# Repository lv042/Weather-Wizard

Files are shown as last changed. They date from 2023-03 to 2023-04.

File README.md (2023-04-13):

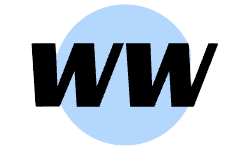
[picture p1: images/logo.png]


# WeatherWizard

WeatherWizard is an Internet of Things (IoT) project that collects and analyzes weather data in real-time. The project is designed to provide users with accurate and up-to-date weather information, as well as insights into climate trends over time.

# Features

- Collects weather data in real-time
- Displays weather data on a web page
- Admin panel to manage the WeatherWizard
- Email notifications
- API Route analytics
- Provides insights into climate trends over time

### Weather measurements:

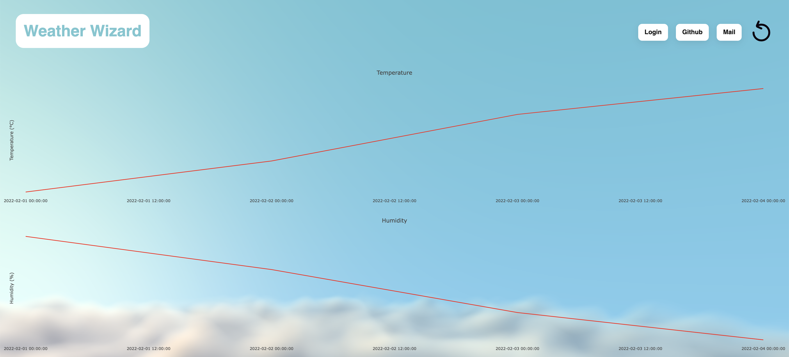
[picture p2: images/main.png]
Weather measurements


### Admin panel:

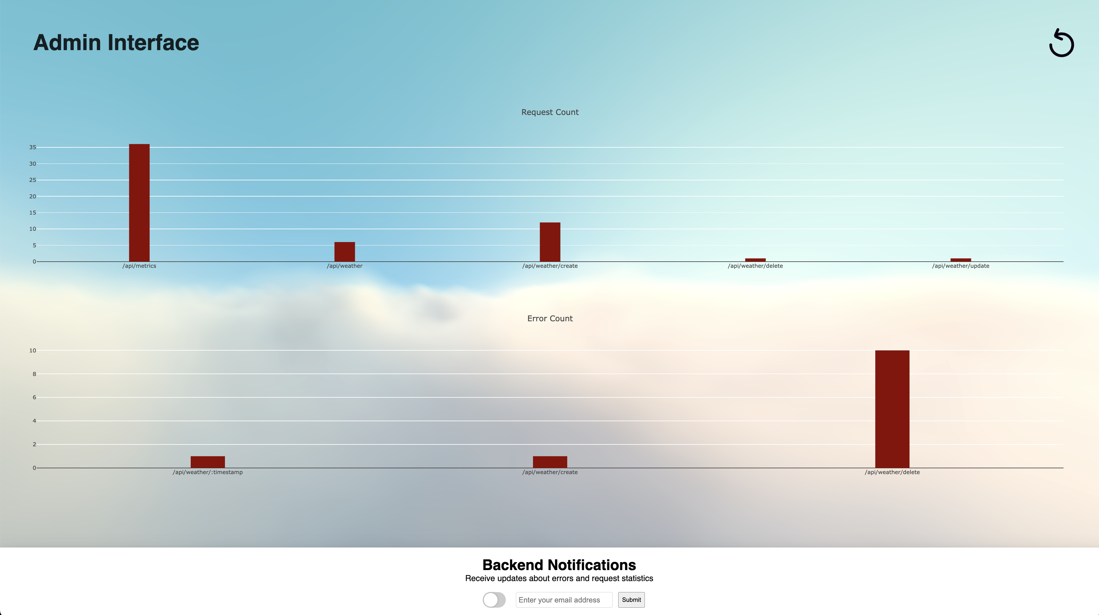
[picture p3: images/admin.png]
Admin panel


### Embedded device:

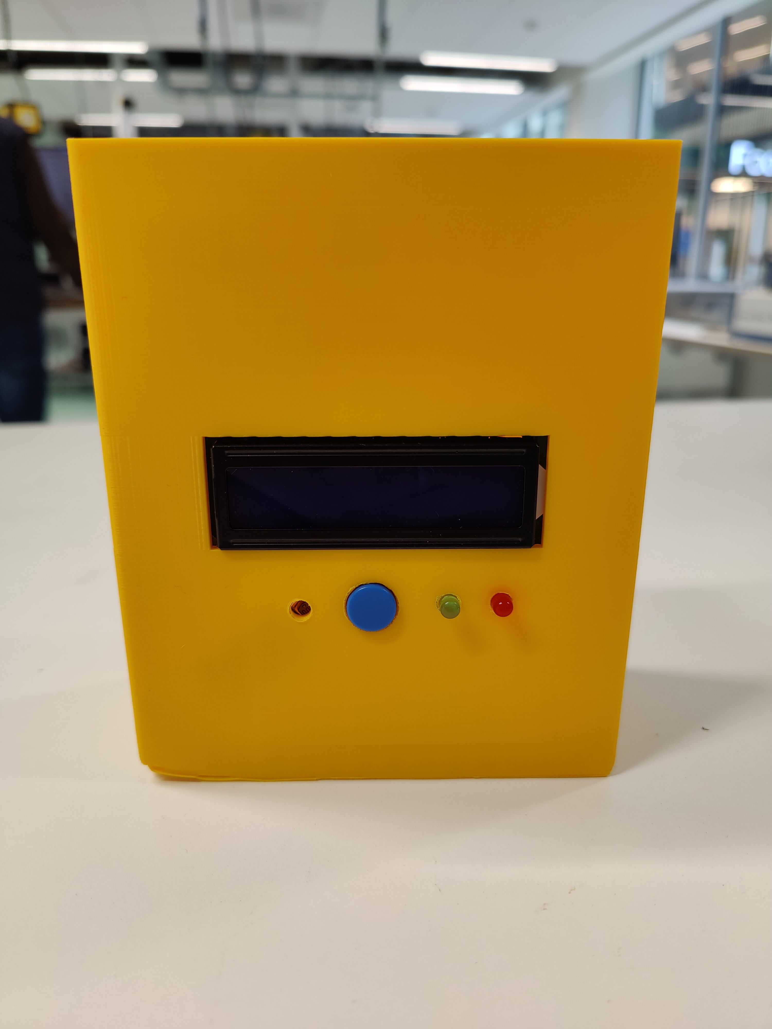
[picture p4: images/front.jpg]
Embedded device


# Getting Started
Clone the WeatherWizard repository and to and follow the instructions provided in the [User manual](./user_manual.md).

# Documentation

The documentation of the project is divided into the following sections:

### General:
- [User manual](./user_manual.md)
- [Architecture overview](./architecture_overview.md)

### Embedded device:
- [System requirements](./system_requirements.md)
- [Software](./emb_software.md)
- [Wiring Diagram & BOM](./bom.md)

### Web application:
- [Database](./db.md)
- [Frontend](./frontend.md)
- [Backend API](./backend.md)
- [New Backend](./improvement.md)

### Physical design:
- [Concept](./physical_design.md)
- [Creation](./creation.md)
- [Failures](./failures.md)

### Research:
- [Research question](./research_question.md)
- [Research](./research.md)
- [Backend implementation](./improvement.md)
- [Changelog](./changelog.md)

# License
WeatherWizard is released under the [Apache License 2.0](./LICENSE).

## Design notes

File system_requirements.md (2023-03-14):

# System Requirements
(Reviewed by Rafail)

## EMBRQ#01
After measuring the data the sensors provide, the data gets send to the server with the "send_data(temperature, humidity, 0, 0, light);"
function. The server then stores the data in a database. The data is then displayed on the website.

POST request:

```json
{
  "timestamp": "2022-03-07 12:00:00",
  "temperature": 25,
  "humidity": 70,
  "pressure": 1013,
  "obstacle_detected": false,
  "light_intensity": 100
}
```

Not all the data is actually collected by the wemos, but it allows for future expansion.

Code:
```cpp
void send_data(float temperature, float humidity, float pressure, int obstacle_detected, float light_intensity) {
  // create the JSON payload string
  String payload = "{\"timestamp\":\"current_time,\"temperature\":" + String(temperature) + ",\"humidity\":" + String(humidity) + ",\"pressure\":" + String(pressure) + 
  ",\"obstacle_detected\":" + String(obstacle_detected) + ",\"light_intensity\":" + String(light_intensity) + "}";
  
  // specify the target URL
  httpClient.begin(client, "https://abc3.loca.lt/index.php?action=weather_data");
  
  // set the content type header to JSON
  httpClient.addHeader("Content-Type", "application/json");
  
  // send the POST request with the JSON payload
  int httpCode = httpClient.POST(payload);
  
  // check if the request was successful
  if (httpCode == HTTP_CODE_OK) {
    Serial.println("Data sent successfully!");
  } else {
    Serial.println("Error sending data!");
  }
  
  // free resources
  httpClient.end();
}
```

## EMBRQ#02
The wemos is able to do a get request to do backend server to ask for a config file. The config file looks currently like this:
```json
{
  "timeout": 5000,
  "retry_count": 3,
  "debug_mode": true
}
```

Code:
```cpp
void get_config(){
  httpClient.begin(client, "https://abc3.loca.lt/index.php?action=config"); // Set up HTTP GET request to server
  int httpCode = httpClient.GET(); // Send HTTP GET request and store response code

  if(httpCode == HTTP_CODE_OK) { // Check if response is successful
    String payload = httpClient.getString(); // Get response payload
    Serial.println(payload); // Print payload to serial monitor
  } else {
    Serial.println("Unable to connect :("); // Print error message if response is unsuccessful
  }

}
```

## EMBRQ#03
The wemos uses the humidity and temperature sensor to measure the temperature and humidity. The light sensor is used to measure the light intensity.
A button is used to turn the Weather Wizard on and off.

Humidity/Temperature and light intensity sensor:
```cpp
void read_sensors(){
  // Humidity is measured
  humidity = dht.readHumidity();
  // temperature is measured
  temperature = dht.readTemperature();
  // light
  light = analogRead(light_intensity_sensor); 
   
  // Checking if the measurements have passed without errors
  // if an error is detected, a error message is displayed here
  if (isnan(humidity) || isnan(temperature)) {
    Serial.println("Error reading the sensor");
    return; /quits the function
  }
}
```

Button:
```cpp
void button_input(){
  int buttonState = digitalRead(buttonPin);

  // If the button is pressed, set running_ww to true
  if (buttonState == HIGH) {
    running_ww = true;
  } else {
    running_ww = false;
  }
}
```

## EMBRQ#04
The Weather Wizard uses the LCD screen to display the temperature, humidity. Furthermore, it has two LEDs, one which is green and one which is red. The green LED is used to indicate that the Weather Wizard is on.
The red LED is used to indicate that the Weather Wizard is off.

Function to display the temperature and humidity on the LCD screen:
```cpp
void run_lcd(){
  lcd.setCursor(0, 0);
  lcd.setBacklight(HIGH);
  // print message
  lcd.print("Temp: ");
  
  char temp_c[5];
  lcd.print(dtostrf(temperature, 3, 2, temp_c));
  
  // set cursor to first column, second row
  lcd.setCursor(0,1);
  lcd.print("Humidity: ");
  
  char hum_c[5];
  lcd.print(dtostrf(humidity, 3, 2, hum_c));
  lcd.print("%");
}
```

Main loop of the Weather Wizard to turn the LEDs on and off:

If Weather Wizard is running the green LED is turned on and the red LED is turned off.
If the Weather Wizard is not running the green LED is turned off and the red LED is turned on.

```cpp
void loop(){
  //check if the button was pressed to turn on Weather Wizard
  button_input();

  if(running_ww){
    //turns on the green LED if the Weather Wizard is running
    digitalWrite(led_red, LOW);
    digitalWrite(led_green, HIGH);

  //after doing a get request the backend sends config file 
  get_config(); // Function to get configuration file from server
  //send data with a post request
  send_data(temperature, humidity, 0, 0, light); // Function to send sensor data to server
    
  run_lcd(); // Function to update LCD screen with sensor data
  read_sensors(); // Function to read sensor values

  //waits 2 sec till it makes new measurements
  delay(2000); // Delay before taking new measurements
  lcd.clear(); // Clear LCD screen
  //lcd clears the screen again
  }
  else{
    //turn on the red light and turn off the green light
    digitalWrite(led_red, HIGH);
    digitalWrite(led_green, LOW);
  }
}
```

## EMBRQ#05
This function sets up the Wi-Fi manager, which allows the user to connect to the Weather Wizard via a web interface. The user can then enter the SSID and password of the Wi-Fi network they want to connect to.
Code:
```cpp
void setup_wifi_manager() {
  WiFiManager wifiManager; // Create a Wi-Fi manager object
  bool con = wifiManager.autoConnect("WeatherWizard AutoConnect", "password"); // Attempt to connect to Wi-Fi using saved credentials or create a new AP with the specified SSID and password
  pinMode(LED_BUILTIN, OUTPUT); // Set the built-in LED pin to output mode

  if(!con) {
      Serial.println("Failed to connect."); // Print error message if unable to connect to Wi-Fi
      digitalWrite(LED_BUILTIN, HIGH); // Turn on LED to indicate error
  } 
  else {
      Serial.println("Connected..."); // Print success message if connected to Wi-Fi
      Serial.println(WiFi.localIP()); // Print the IP address of the device
      digitalWrite(LED_BUILTIN, LOW); // Turn off LED to indicate successful connection
  }
}
```

## Full code 

Go to:

```
./emb/src/main/main.ino
```

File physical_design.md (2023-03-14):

(Reviewed by Rafail)
# Concept

## Target group

The user of the WeatherWizard can be anyone who is interested in monitoring and recording weather data from a specific location. This could include:

- Farmers and agricultural workers who need to track weather patterns for crop management and irrigation purposes.

- Transportation and logistics companies that need to monitor weather conditions to optimize their routes and delivery schedules.

- Construction companies that need to plan their projects around weather conditions.

- Weather enthusiasts who want to track weather data for personal interest or research purposes.

- Government agencies that need to monitor weather conditions for disaster preparedness and response.

## Needs and Goals

- Weather resistance: Since the WeatherWizard is constantly exposed to various weather conditions such as rain, sunlight, wind, etc., the housing should be robust and weather-resistant to protect the sensors and electronics from damage.

- Waterproofing: The enclosure should be waterproof to prevent water from entering the enclosure and damaging the sensors or electronics.

- Space requirement: The enclosure should provide enough space to accommodate all sensors, batteries, and transmission technology.

- Material: The enclosure material should be robust, durable, and corrosion-resistant to ensure a long life for the WeatherWizard -> ABS plastic

- Mounting options: The enclosure should provide suitable mounting options to mount the WeatherWizard in a suitable location, such as on a wall or pole.

- Access to the interior: The housing should allow easy access to the inside to replace or maintain the batteries or electronics if necessary.

- Easy assembly: The enclosure should be easy to assemble, disassemble, and transport, making it convenient for installation and relocation.

- Cost: The enclosure should be cost-effective to ensure that the WeatherWizard can be manufactured at a reasonable price.

- Noise reduction: The housing should be designed to reduce any noise or vibration caused by the sensors or electronics, which can affect the accuracy of the collected data. (Altough there are no moving parts in the WeatherWizard by now)

- Ventilation: The enclosure should be designed to allow for proper ventilation to allow accurate measerments by the sensors.

- Aesthetics: The enclosure should be designed to be aesthetically pleasing to ensure that the WeatherWizard is not an eyesore.

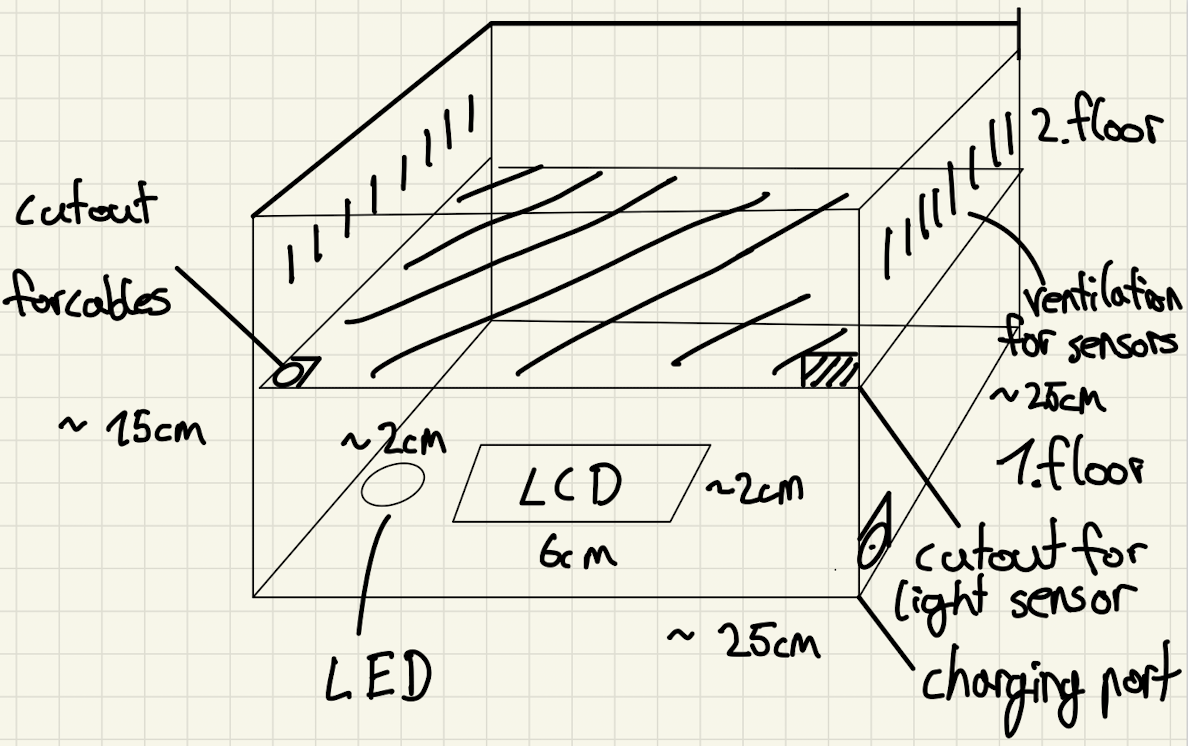
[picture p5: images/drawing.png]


The design is seperated in two floors the first floor is for the main hardware and the second is for the sensors. The reason for that is that some of the sensors need ventilation to make more accurate messearments.

## Smart requirements

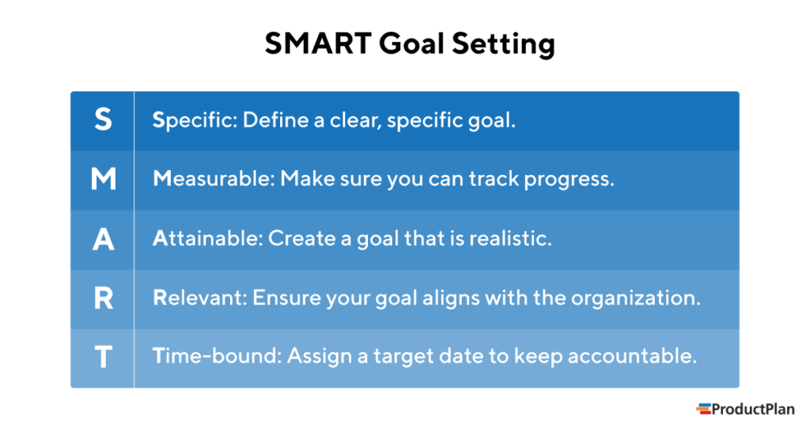
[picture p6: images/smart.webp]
Smart


Specific: All the goals mentioned above are specific and clear.

Measurable: I made a timeline in the docks, where I can see how much time I spend on each part of the project.

Attainable: All the requirements mentioned above are realistic and achievable.

Relevant: All the requirements mentioned above are relevant to the project.

Time-bound: My time target is to finish the physical design in one week before the deadline, so I still have time to make changes and improvements.

# Digital manufacturing materials and methods

## The chosen device

3D printing is a process in which a digital 3D model is converted into a physical object layer by layer using a 3D printer. To do this, the printer uses different materials, such as plastics or metals, which are applied layer by layer and fused together.

## The chosen material

For the enclosure of the weather station, ABS (Acrylonitrile Butadiene Styrene).  ABS is known for their high strength, durability, and resistance to impact and weathering, making them ideal for protecting the sensitive electronic components of the WeatherWizard from the elements.

## Reasons for the selected production:

- Customizability: 3D printing allows for easy customization of the design of the weather station chassis, enabling the creation of unique and specialized designs to meet specific requirements (Altough the shape is right now very simple, but it might be changed in the future)

- Speed: 3D printing allows for fast production of the weather station chassis, with the ability to print parts on demand and with minimal lead time.

- Cost-effective: 3D printing is a cost-effective option for producing a small casing the weather station chassis (The final draft of the weather station which is currently printing, costed me 10 euro's)

- Durability: 3D printing allows for the production of durable parts that can withstand the elements and last for a long time.

## Disadvantages of the selected production:

- Limited material choices: While 3D printing has come a long way in terms of materials, the range of available materials is still limited compared to traditional manufacturing methods.
- Hard to repair: 3D printing is not suitable for repairing broken parts.
- Hard to recycle: 3D printing is not suitable for recycling.
- Limited print size: The size of 3D printed objects is limited by the size of the 3D printer.
- Limited production speed: 3D printing can be a slow process, especially for large objects.

# DIGITAL DESIGN

## Chosen software

First I used Tinkedcad, but later switched to FreeCAD. I used FreeCAD because it is more powerful and has more features. Tinkercad might be better for beginners, but FreeCAD is more suitable for more complex designs.

Update: Unfortunately I had to switch back to Tinkercad because FreeCAD learning curve is too steep for the time I have left.

## Stages of the design process

1. Determine the purpose and requirements of the casing
2. Take accurate measurements
3. Create a 3D model of the object using CAD software
4. Select the appropriate printer and material
5. Slice the 3D model into layers using slicing software
6. Set the printing parameters, such as the layer height and printing speed
7. Send the sliced model to the 3D printer and start the printing

# Project files of the design

Go to:
```
./physical-design/........
```

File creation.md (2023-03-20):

# Physical Design - Create

(Reviewer Luca(not me))

## Requirements

The most important requirements are for me:

- The device should be able to withstand the weather conditions in the Netherlands
- Weather Wizard should have cutouts for the sensors, button, led's and the LCD screen
- The casing should be easy to assemble after printing
- The casing should be easy to print
- Weather Wizard should provide a lot of space to be expandable with more sensors
- The casing should have a ventilation hole to guarantee accurate sensor readings

## Testing

Criteria I can test:

- The casing should be easy to assemble after printing -> You just have to plug in sensors, button, led's and the LCD screen and
glue the roof on the casing

- Measurements -> All the components fit in the casing as shown later in the final design

- Aesthetics -> The casing looks nice and is easy to print

- Ventilation for sensor readings -> The casing has a ventilation hole at the bottom of the casing

- Rain test -> I put the casing in the shower, and it was still working after 10 minutes

Update: I have tested the case in the rain, and it is not completely waterproof, but rather water-resistant . I think that the optimal solution for this problem would be to use hot glue to seal the ceiling of the case.
This is an image of before the test:

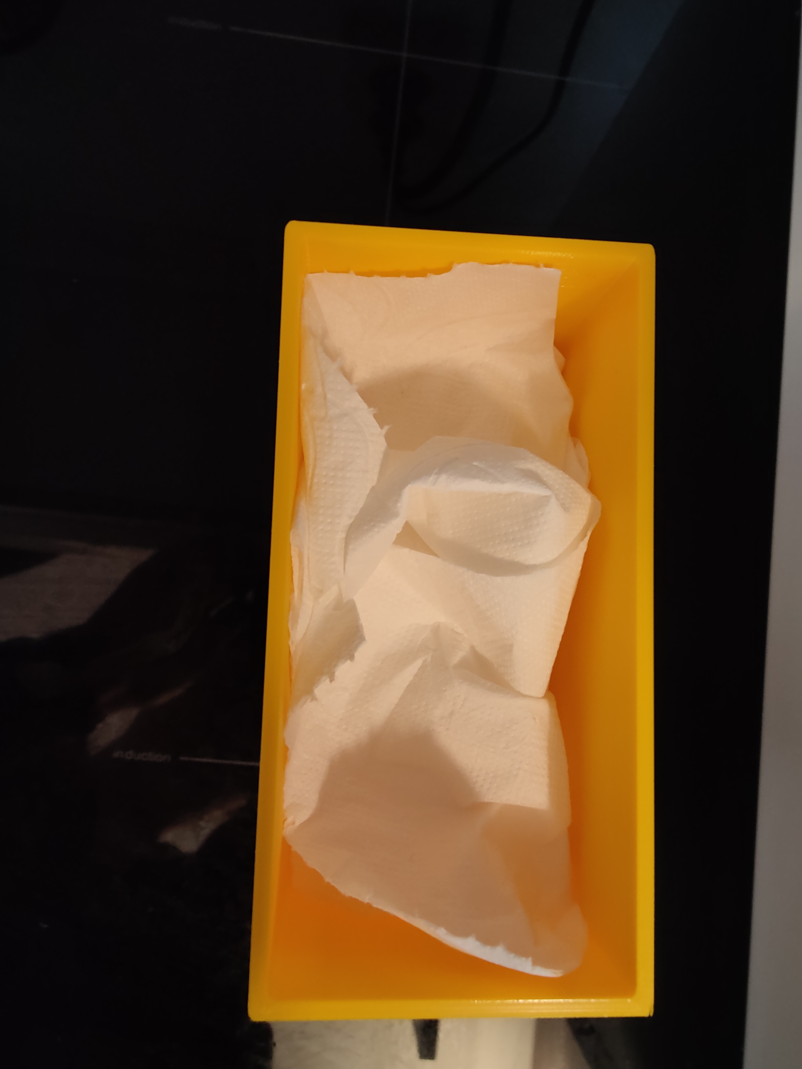
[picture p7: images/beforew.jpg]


This is an image during the test:

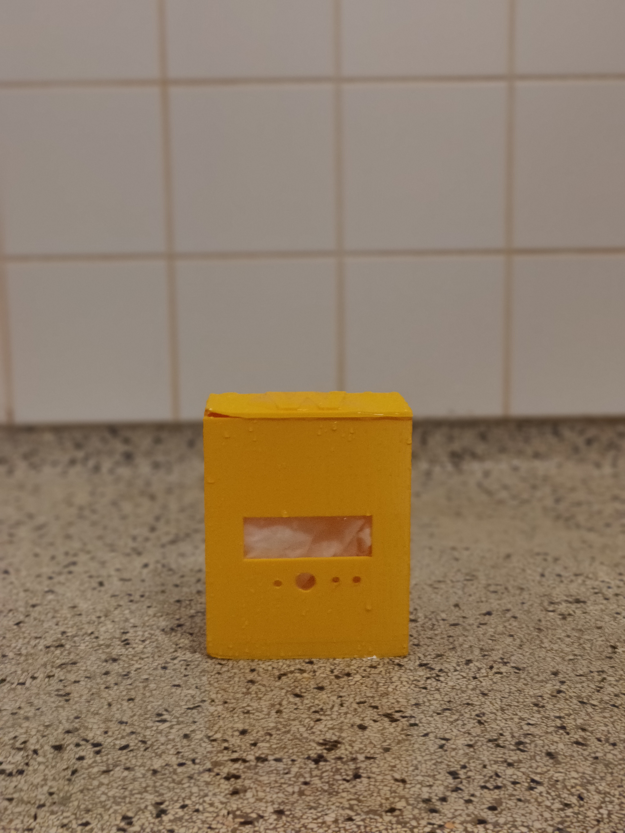
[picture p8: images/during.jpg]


This is an image after the test:

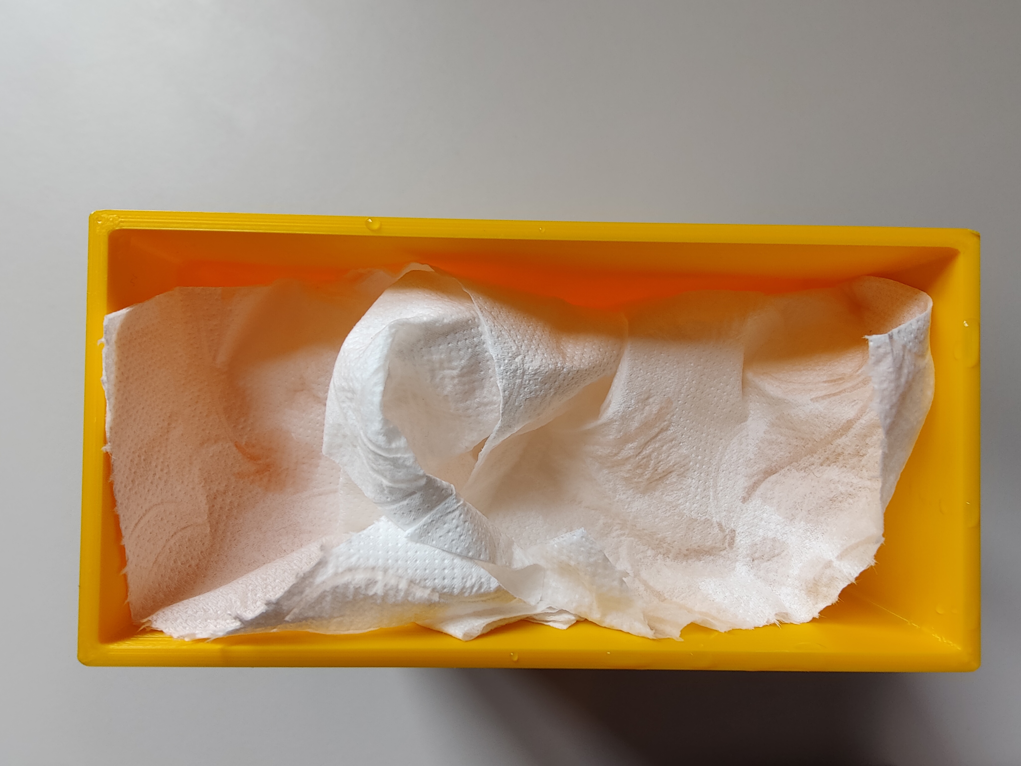
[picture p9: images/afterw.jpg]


You can clearly see that some water got inside the casing, but not enough that you can't hot glue the ceiling of the casing.

- Drop test -> I dropped the casing from 1 meter for 20 times, and the casing was still intact

Update: These are images of the casing after the drop test:

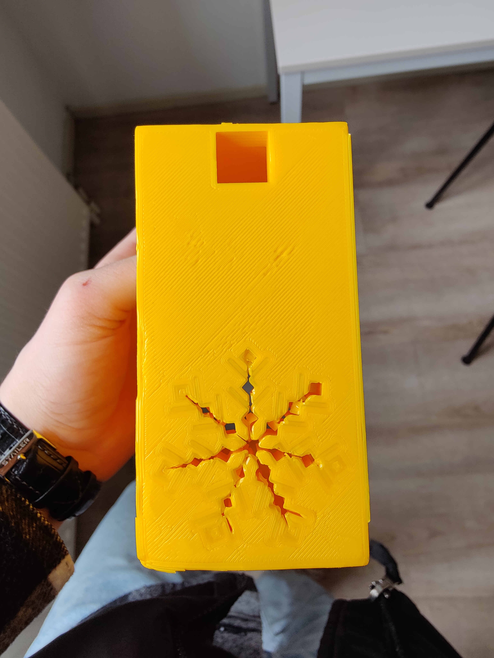
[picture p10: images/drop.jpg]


You can see that there are no major damages to the casing. The scratches in the bottom are probably rather from printing errors than from the drop test. In my opinion the casing can withstand most environmental conditions as long as it is made waterproof.

After performing the drop test, I noticed that the casing was not completely intact. The casing was still working, but the casing was not as sturdy as I thought it would be. I think that the optimal solution for this problem would be to use hot glue to seal the ceiling of the case.

- Space for expansion -> The casing has a lot of space to be expandable with more sensors

- Assembly -> Weather Wizard is very easy to print. The files for the 3D-printer are provided and it is easy to assemble afterwards

## Prototype

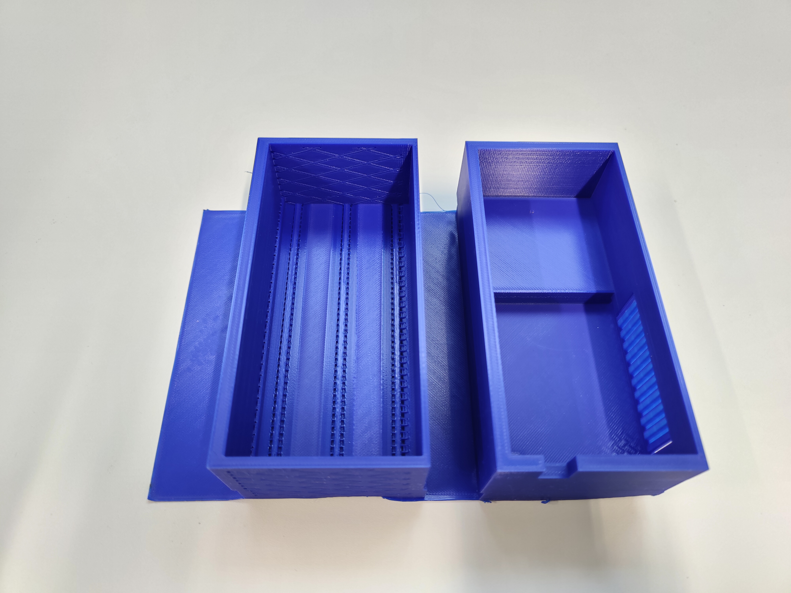
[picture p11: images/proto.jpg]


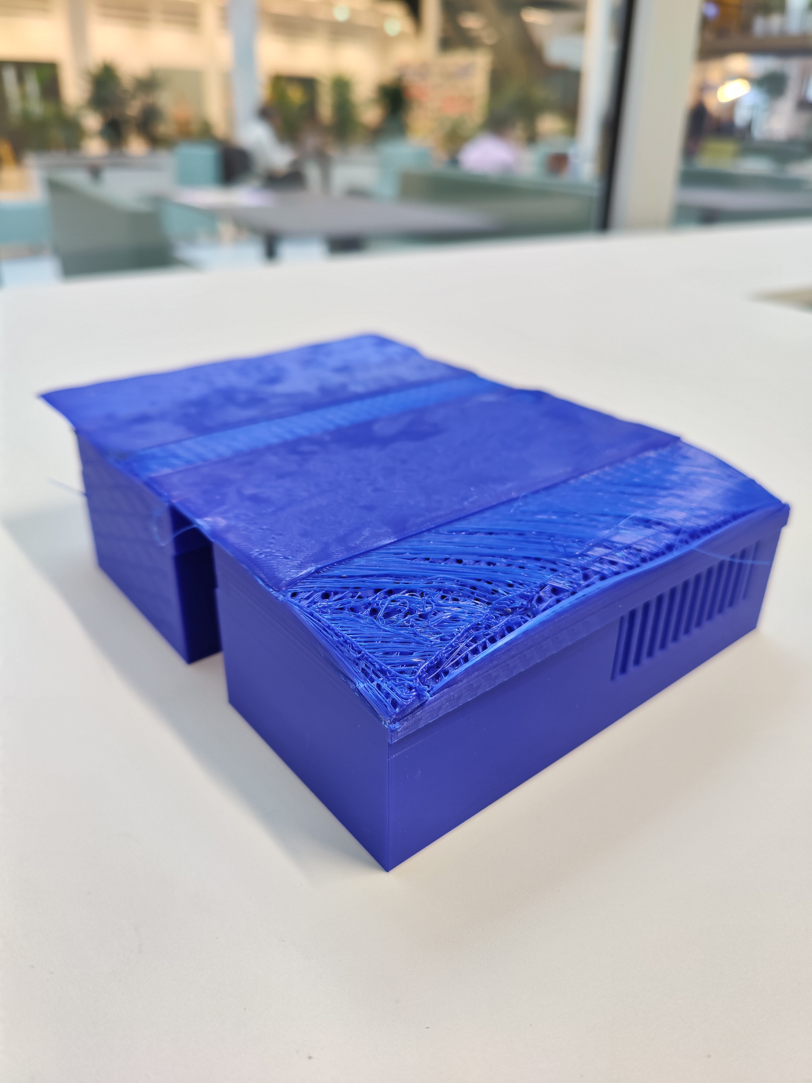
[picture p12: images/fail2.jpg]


Although this prototype already looks quite good. I still want to make some changes to the casing. The changes include: 

- Merging the two smaller cases into one big case to make it easier to print and assemble

- Putting the ventilation hole at the bottom of the casing, so rainwater can't get inside the casing like before

- Removing the holes from the print, but instead drill the holes in the casing after printing which is easier to do and more accurate

- Improve printing quality -> The bottom of the prototype is not printed well, so I want to improve the printing quality

## Final Design

First, after merging the two smaller cases and adding the ventilation at the bottom, this was the design:

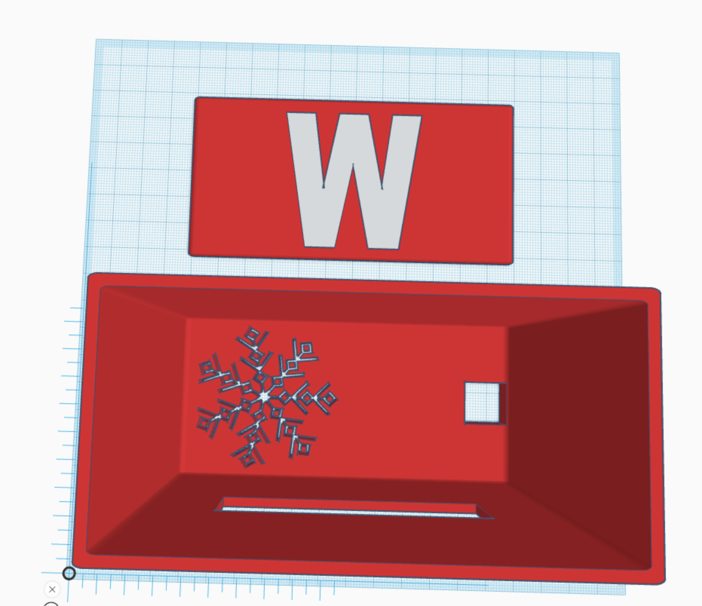
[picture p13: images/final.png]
Final Design


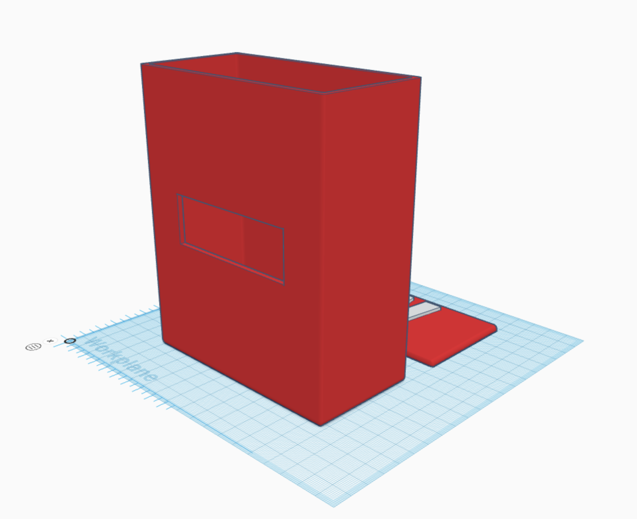
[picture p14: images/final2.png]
Final Design


A snowflake made a great shape for the ventilation hole, because it was easy to print and was fitting for a weather station. The
W on the top of the casing stands for Weather Wizard. The other cutout at the bottom is for the cable of the Wemos d1 mini.

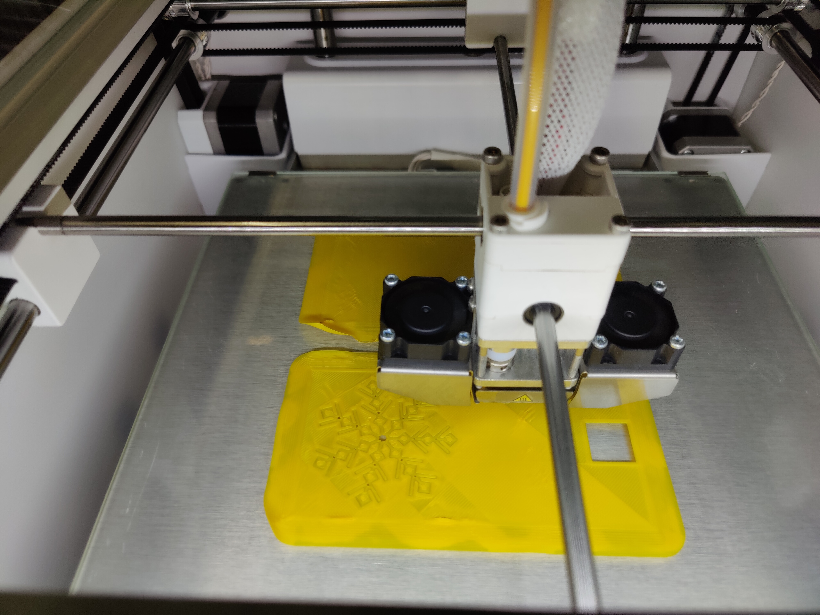
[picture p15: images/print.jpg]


This was the first print of the casing. Although the print had some imperfections, it was good enough for the final version.
I used a 0.2 mm layer height and 20% infill. The print took about 17 hours and 30 minutes. The print was made with PLA filament.
I used auto generated support for the snowflake and the hole of the lcd screen. The support was easy to remove afterwards. The whole 
casing was printed on a brim, so it would stick to the build plate. The Cura slicer was used for the slicing and the printer was a
Ultimaker 2+ Connect.

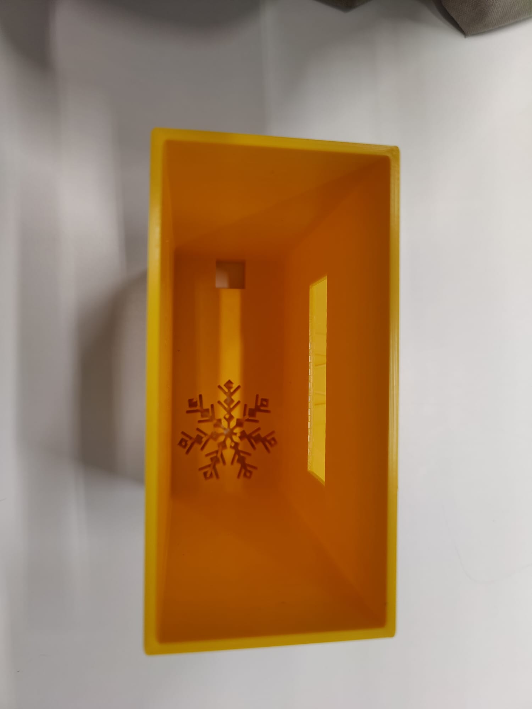
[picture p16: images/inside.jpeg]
Inside


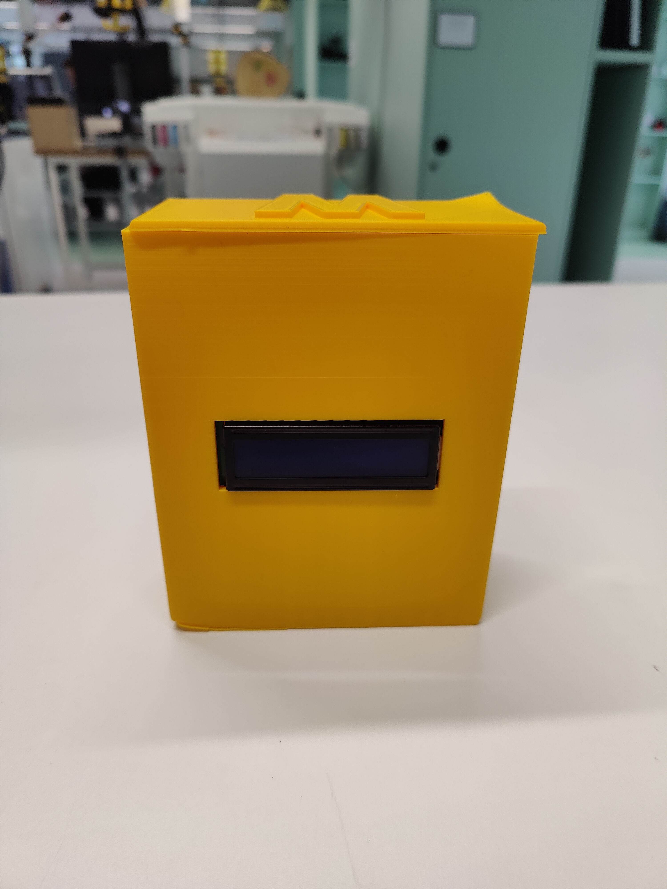
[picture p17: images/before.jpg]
Before


This was the first look of the casing after printing and inserting the lcd screen.

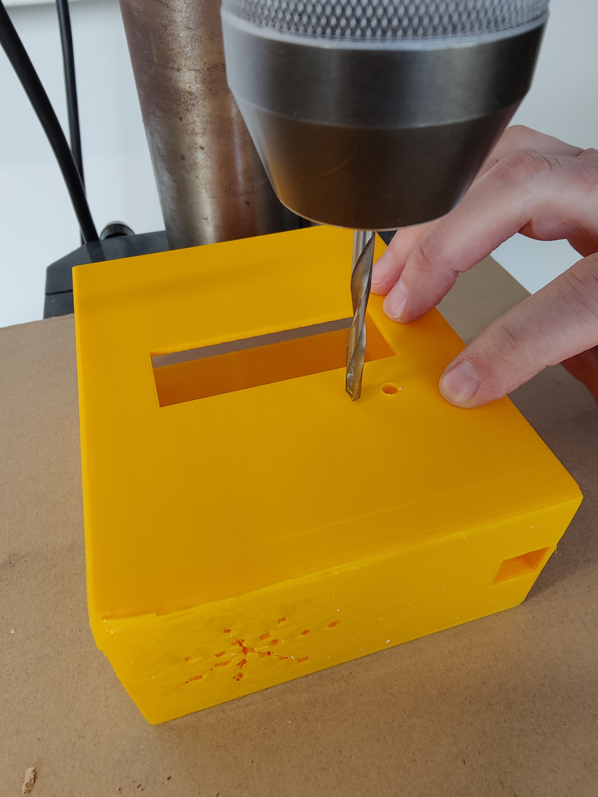
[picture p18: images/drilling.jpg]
drilling


Next, I still had to drill the holes for the sensors, button, led's and the LCD screen. Firstly, I measured the length of the components
and marked the holes on the casing. Then I compared the measurements with the drill bits I had. I used a 3mm and 5 mm drill bit for the
the sensors and led's. The button needed the 5 mm drill bit. It is important that a drill bit for plastic is used, otherwise you will
damage the drill bit. 

After

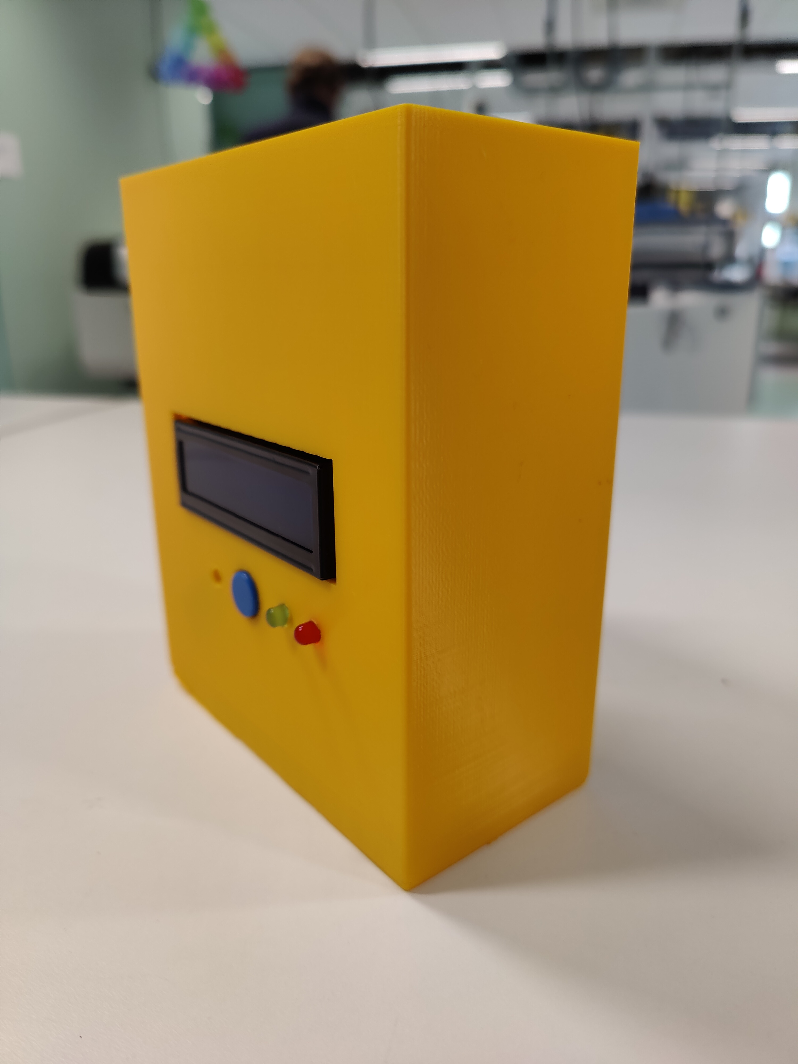
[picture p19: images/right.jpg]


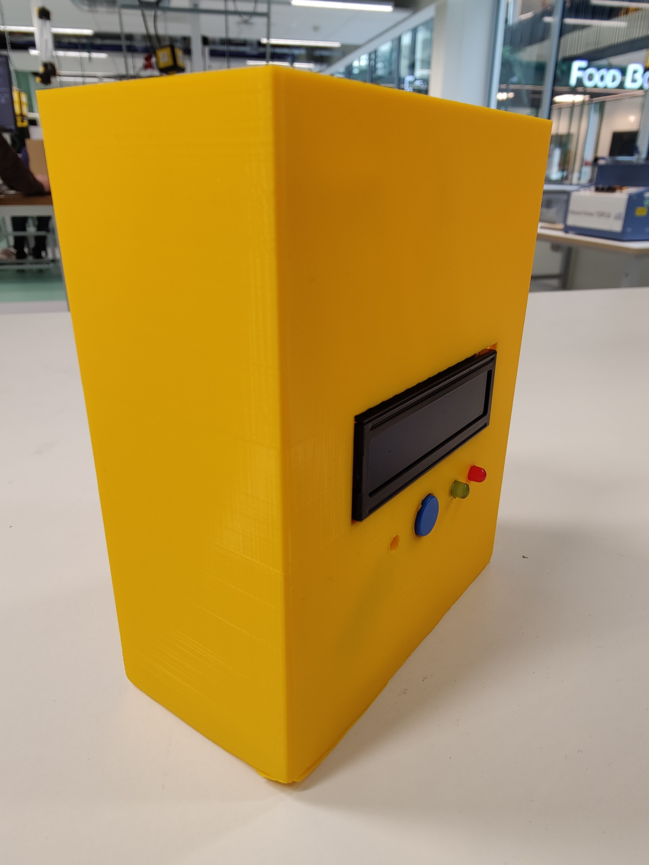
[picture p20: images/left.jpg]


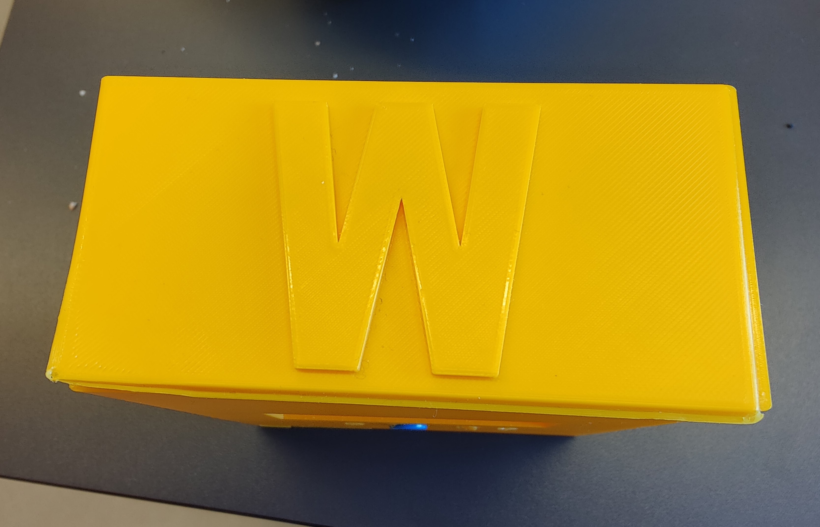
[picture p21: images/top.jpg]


For the final version, I would glue the components with hot glue to make sure they don't fall out of the casing, but 
for now I duck taped them in the casing, because I still want to use the components after the project.

## Manufacturing process

I printed in with the quality setting, which already took 17 hours and 30 minutes. To have more detail you could print with the smallest nozzle, but
this would take more than 24 hours to print and would cost way too much time for the blueprint phase.

#### Chosen material 

I chose PLA yellow Ultimaker filament, because:

- It is easy to print with
- It is easy to remove the support
- It is easy to glue the components in the casing
- It is easy to drill the holes in the casing
- It is environmentally friendly
- It is cheap
- It allows for a wide range of colors and finishes

#### Manufactoring device

The main reason, because I printed with the Ultimaker 2+ Connect, is because it was the main printer of the Makerslab, but it is also a good printer.

Most of its special features, I didn't even have to use:

- Single extrusion with swappable nozzles
-  Cloud-enabled remote 3D printing
-  Filter up to 95% of UFPs (optional)
-  Print with 9 materials (including PP & PC)

#### Logging of the manufacturing process is described

Of course, I could only log the beginning of the print and the final product of the print, because the print always was running the whole night.

#### Files

The stl files contain the basic structure of the file and the 
ufp files contain the additional information for the printer. 
The ufp files are used to print the casing with the Ultimaker 2+ Connect.

The files can be found here in the root of the repo:
```
./physical-design
```

Prototype files:

- [Prototype.ufp](./physical-design/prototype.ufp)
- [Prototype 0.1.stl](./physical-design/prototype%200.1.stl)
- [Prototype 0.15.stl](./physical-design/prototype%200.15.stl)
- [Prototype 0.2.stl](./physical-design/prototype%200.2.stl)
- [Prototype 0.25.stl](./physical-design/prototype%200.2%20rotated.stl)

Final design:

- [Final Design.ufp](./physical-design/Weather%20Wizard%20Final.ufp)
- [Final Design.stl](./physical-design/Weather%20Wizard%20Final.stl)

#### Optimisations during the manufacturing process:

- During the print one of the early models was not compatabile with the printer, because the required support was too big for the printer, and coudln't be removed afterwards. So I had to redesign the casing to make it compatible with the printer.
- I drilled the holes of the casing, instead of printing them, because it was easier to do, more accurate and allowed more flexibility for the components.
- After using the printing option with the smallest nozzle, which took longer than 24 hours, I decided to use the normal quality option, which took 17 hours and 30 minutes. This was a good compromise between time and quality, because
the quality was good enough for the final version.

#### Future possible Optimisations

- For mass production, I would use a different printer, because the Ultimaker 2+ Connect is not the fastest printer, and it is not the cheapest printer, but also including the holes in the casing 
would make the assembly easier and more accurate.

- More accurate holes for the components

- Glue the components in the casing with hot glue

- More accurate printing quality, could be achieved by printing with a smaller nozzle size

#### Reached Requirements

All the mentioned requirements are reached, except for the easy printing, because the time to print is quite long. But the print is easy to assemble afterwards.

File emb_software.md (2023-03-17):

# Embedded Software

(Reviewed by Rafail)

This document describes the embedded software of the Weather Wizard. The embedded software is the code that runs on the microcontroller. The microcontroller is the brain of the Weather Wizard. It is responsible for reading the sensors, displaying the data on the LCD screen, and sending the data to the backend.

## Information about the code 

Program code contains comment in the top the file stating author information, license type, and goal of this part of the program and has a nice readable layout. License type is an existing license type like FreeBSD, or CC, or individual copyright (C) containing a year.

```
/* Author: Luca von Kannen
 * License: Apache License, version 2.0.
 * Goal: This file contains code to operate the WeatherWizard and to connect it to the backend.
 */
```

## Code structure and syntax

Program code is indented with tabs or spaces. All code blocks contain matching opening and closing curly brackets { }.
Syntax highlighting is visible.

```
See full code below.
```

## Macros and constants

Program code contains no magic numbers and all macro definitions and constants are defined in one place which improves maintainability of your code.

```cpp
// DHT input pin
#define DHTPIN 0   
// The DHT-11 is initialized
#define DHTTYPE DHT11 // DHT 11
DHT dht(DHTPIN, DHTTYPE);
 
//parameter for my home wifi
const char* ssid     = "Hi"; // Wi-Fi network name
const char* password = "prinsengracht225d"; // Wi-Fi network password
 
// set the LCD number of columns and rows
int lcdColumns = 16;
int lcdRows = 2;

float humidity = 0;
float temperature = 0;
int light = 0; // variable to store light intensity value

int led = 15; // GPIO pin for the LED
int light_intensity_sensor = A0; // GPIO pin for the light intensity sensor
```

## Code documentation

- All control constructs are commented. In the comments it is documented what a control construct does or why it is needed, or what decisions are made.
- All functions are commented. In the comments it is documented what a function does and what it's input and output (return value) is.
- Comments are easily readable and within the max character per line limits.

```
See full code below.
```

## Code Reusability

- There is no duplication of code.
  - Libraries are used to reuse other people's program code.
  - Functions are used as reusable building blocks for your own code.
  - Some handy functions are placed in libraries for reuse in other applications.

```
See full code below. All setups and loops are in their own indepentend functions.  
```

## Naming conventions

- All variables follow the camel case convention and have names reflecting the variables' use.
- All macro constants (#define) are in SCREAMING_SNAKE_CASE.
- All function names are in lower camel case.

```cpp
/* Author: Luca von Kannen
 * License: Apache License, version 2.0.
 * Goal: This file contains code to operate the WeatherWizard and to connect it to the backend.
 */

#include <LiquidCrystal_I2C.h> // Library for interfacing with the LCD screen
#include <ESP8266WiFi.h> // Library for connecting to WiFi
#include <ESP8266HTTPClient.h> // Library for making HTTP requests
#include <WiFiClient.h>
#include <WiFiManager.h>
// Adafruit_DHT library for interfacing with the DHT11 temperature and humidity sensor
#include "DHT.h"

// DHT input pin
#define DHTPIN 0   
// The DHT-11 is initialized
#define DHTTYPE DHT11 // DHT 11
DHT dht(DHTPIN, DHTTYPE);
 
//parameter for my home wifi
const char* ssid     = "Hi"; // Wi-Fi network name
const char* password = "prinsengracht225d"; // Wi-Fi network password
 
// set the LCD number of columns and rows
int lcdColumns = 16;
int lcdRows = 2;

int buttonPin = D3; 
float humidity = 0; //variable to store the humidity
float temperature = 0; //variable to store the temperature
int light = 0; // variable to store light intensity value

int led_green = D0;
int led_red = D5; // GPIO pin for the LED
int light_intensity_sensor = A0; // GPIO pin for the light intensity sensor

bool running_ww = false; //if the Weather Wizard is currently running
String current_time = "";

// create the HTTP client object
WiFiManager wm; // Object for managing Wi-Fi connection
LiquidCrystal_I2C lcd(0x27, lcdColumns, lcdRows); // Object for interfacing with the LCD screen 
WiFiClient client; // Object for managing Wi-Fi client connection
HTTPClient httpClient; // Object for making HTTP requests

void setup() {
  //sets baud rate to 115200
  Serial.begin(115200);
  
  //wifi
  setup_wifi_manager(); // Function to set up Wi-Fi manager
  //config for lcd
  setup_lcd(); // Function to set up LCD
  setup_dht(); // Function to set up DHT11 sensor
  
  pinMode(led_red, OUTPUT); // Set LED pin to output mode
  pinMode(buttonPin, INPUT);

  //some sensors ned some time before they start working
  delay(2000); // Delay to allow sensors to stabilize
}

void loop(){

  //check if the button was pressed to turn on Weather Wizard
  button_input();

  if(running_ww){
    //get current time
    get_current_time();

    //turns on the green LED if the Weather Wizard is running
    digitalWrite(led_red, LOW);
    digitalWrite(led_green, HIGH);

  //after doing a get request the backend sends config file 
  get_config(); // Function to get configuration file from server
  //send data with a post request
  send_data(temperature, humidity, 0, 0, light); // Function to send sensor data to server
    
  run_lcd(); // Function to update LCD screen with sensor data
  read_sensors(); // Function to read sensor values

  print_to_console();
  //waits 2 sec till it makes new measurements
  delay(2000); // Delay before taking new measurements
  lcd.clear(); // Clear LCD screen
  
  }
  else{
    //turn on the red light and turn off the green light
    digitalWrite(led_red, HIGH);
    digitalWrite(led_green, LOW);
  }
}

void get_current_time() {
  
  httpClient.begin(client, "http://worldtimeapi.org/api/ip");
  int httpCode = httpClient.GET();
  
  //does a get request to receive the current time from this api
  int httpResponseCode = httpClient.GET();
  if (httpResponseCode == HTTP_CODE_OK) {
    String payload = httpClient.getString();
    int startIndex = payload.indexOf("datetime") + 12;
    int endIndex = startIndex + 19;
    current_time = payload.substring(startIndex, endIndex);
    //assign the global variable current_time to the response
  } else {
    Serial.println("HTTP request failed");
  }
}

void button_input(){
  int buttonState = digitalRead(buttonPin);

  // If the button is pressed, set running_ww to true
  if (buttonState == HIGH) {
    running_ww = true;
  } else {
    running_ww = false;
  }
}

void get_config(){
  httpClient.begin(client, "https://abc3.loca.lt/index.php?action=config"); // Set up HTTP GET request to server
  int httpCode = httpClient.GET(); // Send HTTP GET request and store response code

  if(httpCode == HTTP_CODE_OK) { // Check if response is successful
    String payload = httpClient.getString(); // Get response payload
    Serial.println(payload); // Print payload to serial monitor
  } else {
    Serial.println("Unable to connect :("); // Print error message if response is unsuccessful
  }

}

void send_data(float temperature, float humidity, float pressure, int obstacle_detected, float light_intensity) {
  // create the JSON payload string
  String payload = "{\"timestamp\":\"current_time,\"temperature\":" + String(temperature) + ",\"humidity\":" + String(humidity) + ",\"pressure\":" + String(pressure) + 
  ",\"obstacle_detected\":" + String(obstacle_detected) + ",\"light_intensity\":" + String(light_intensity) + "}";
  
  // specify the target URL
  httpClient.begin(client, "https://abc3.loca.lt/index.php?action=weather_data");
  
  // set the content type header to JSON
  httpClient.addHeader("Content-Type", "application/json");
  
  // send the POST request with the JSON payload
  int httpCode = httpClient.POST(payload);
  
  // check if the request was successful
  if (httpCode == HTTP_CODE_OK) {
    Serial.println("Data sent successfully!");
  } else {
    Serial.println("Error sending data!");
  }
  
  // free resources
  httpClient.end();
}

void read_sensors(){
  // Humidity is measured
  humidity = dht.readHumidity();
  // temperature is measured
  temperature = dht.readTemperature();
  // light
  light = analogRead(light_intensity_sensor); 
   
  // Checking if the measurements have passed without errors
  // if an error is detected, a error message is displayed here
  if (isnan(humidity) || isnan(temperature) || isnan(light)) {
    Serial.println("Error reading the sensor");
    return; //quits the function
  }
}

void print_to_console(){
    // Output to serial console
  Serial.println("-----------------------------------------------------------");
  Serial.print("Humidity: ");
  Serial.print(humidity);
  Serial.print(" %\t");
  Serial.print("Temperature: ");
  Serial.print(temperature);
  Serial.print(char(186)); //Output <°> symbol
  Serial.println("C ");
  Serial.println("-----------------------------------------------------------");
  Serial.print("Light intensity: ");
	Serial.println( light, DEC);
  Serial.println("-----------------------------------------------------------");
}

void run_lcd(){
  lcd.setCursor(0, 0);
  lcd.setBacklight(HIGH);
  // print message
  lcd.print("Temp: ");
  
  char temp_c[5];
  lcd.print(dtostrf(temperature, 3, 2, temp_c));
  
  // set cursor to first column, second row
  lcd.setCursor(0,1);
  lcd.print("Humidity: ");
  
  char hum_c[5];
  lcd.print(dtostrf(humidity, 3, 2, hum_c));
  lcd.print("%");
}

void setup_lcd(){
  lcd.begin(5, 4);// initialize LCD
  lcd.init();
  // turn on LCD backlight                      
  lcd.backlight();
}

void setup_dht(){
  //humidity and temperture 
  Serial.println("KY-015 test - temperature and humidity test:");
  // Measurement is started
  dht.begin();
}
void connectToWiFi(const char* ssid, const char* password) {
  //this code is only needed to connect to a specific wifi
  //this method won't be called because currently the wifi manager is used
  delay(10);
  Serial.println('\n');

  WiFi.begin(ssid, password);
  Serial.print("Connecting to ");
  Serial.print(ssid);
  Serial.println("...");
  
  int i = 0;
  while (WiFi.status() != WL_CONNECTED) {
    delay(1000);
    Serial.print(++i);
    Serial.print(' ');
  }

  Serial.println('\n');
  Serial.println("Connection established!");
  Serial.print("IP address:\t");
  Serial.println(WiFi.localIP());
}

void setup_wifi_manager() {
  WiFiManager wifiManager; // Create a Wi-Fi manager object
  bool con = wifiManager.autoConnect("WeatherWizard AutoConnect", "password"); // Attempt to connect to Wi-Fi using saved credentials or create a new AP with the specified SSID and password
  pinMode(LED_BUILTIN, OUTPUT); // Set the built-in LED pin to output mode

  if(!con) {
      Serial.println("Failed to connect."); // Print error message if unable to connect to Wi-Fi
      digitalWrite(LED_BUILTIN, HIGH); // Turn on LED to indicate error
  } 
  else {
      Serial.println("Connected..."); // Print success message if connected to Wi-Fi
      Serial.println(WiFi.localIP()); // Print the IP address of the device
      digitalWrite(LED_BUILTIN, LOW); // Turn off LED to indicate successful connection
  }
}
```

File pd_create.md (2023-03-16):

## Prototype

## Create

## Conclusion

MANUAL MANUFACTURING

## Requirements:
Sufficient and realistic requirements should be chosen for the manual manufacturing of the weather station case. The requirements that have the most impact on the design, realization, or use of the product should be prioritized.

## Testing:

- Physical inspection: Does the model look like the design? The dimensions are correct and that the walls are of the desired thickness.

- Fit testing: Fit the components in the case? After noticing that it is much easier to make cutouts yourself

- Durability testing: How resistant is the case to impacts? -> Drop test 

- Weather resistance testing: Test how resistant the case is to rain, snow, and sunlight. Although it is hard to test the snow in the Netherlands. -> Test if water gets inside during 60 sec of rain

- Long-term testing: Unfortunately, I did not have the time to test the case in a long term scenario.

## Prototype:
A prototype of the weather station case should be realized using manual manufacturing techniques that are in line with the chosen digital manufacturing techniques and that are available. The approach should be documented clearly, and any changes made for the final version should be described.

I had to print my prototype scaled to 50% because my orignal model was too big for the 3D-printer.

## Digital Manufacturing:
As mentioned before I used Tinkerpad for developing the casing. Tinkerpad may look rather playful, but it allows you to create very complex designs. 

## Requirements:
The chosen device, material, and manufacturing settings should be described for the digital manufacturing of the weather station case.

I have printed my work with the blablablababalbalubbluab printer. I used  0.2mm ABS plastic layers to have a more detailed result and 20% infill to make it more strong. I used the material PLA because it is strong and easy to print with. For the main development I used Tinkerpad, the development process with Tinkerpad is also described in detail on Concept document. 
To slice the model I used Cura, because it is easy to use and has a lot of features and is the slicer that is used by the Makerlab. I used the settings mentioned above and worked with support material the cutouts of the led screen and the venting holes. I also used a brim to make sure that the model would stick to the build plate. Printing the final model in detail took about 20 hours,
but only 15 were needed for the draft model.

## Optimizations:
For the final product I changed a lot of details of the prototype. First of all I changed the size of the casing, that it was also printable with the smaller 3D-printers of the Makerlab.
Instead of having printed wholes in the casing for the sensors and led, I decided that it would be better to drill the wholes myself. That way I could make sure that the wholes were in the right place and the right size. 

Not realised improvements:

Although I planned to have a waterproof casing currently it is not completely waterproof. I tried to make the ventalation holes as small as possible, but I think that I could have made them even smaller. I think the optimal solution for this problem would be ventilation that are faced downwards, so that the water would not be able to get in.

## Manufacturing Process:
The manufacturing process should be logged with pictures and/or videos as proof. All steps should be clearly logged and can be replicated, and any different aspects that need to be paid attention to should be described.

1. Design in Tinkerpad and export to STL file
2. Slice the STL file in Cura and export to a usable file for the 3D-printer
3. Put the file on a USB-stick and put it in the 3D-printer
4. Heat up the nozzle to the right temperature and wait till the old filament is extruded
4. Load your filament and wait till the filament is extruded
5. Load your files and start the print
6. Wait till the print is finished :) 
7. Remove the print from the build plate and remove the support material
8. Drill the wholes for the sensors and the led's

## Product:

The final product should be demonstrated in pictures and/or videos in all angles, showing the workings of the product. It should be described which requirements have been met and which have not. Future recommendations for improvements should be given. The product should be clean and usable for the selected criteria, and if possible, should also look good and/or be durable.

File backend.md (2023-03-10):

# Backend documentation
(Reviewed by Luca(not me))

This API provides CRUD (Create, Read, Update, Delete) operations for managing weather data.

## Methods:

- POST /?action=weather_data - Creates a new weather data point
- PUT /?action=weather_data - Updates an existing weather data point
- DELETE /?action=weather_data - Deletes an existing weather data point
- GET /?action=weather_data - Retrieves all the weather data points

## Parameters:

- timestamp: The timestamp of the weather data point (required)
- new_timestamp: The new timestamp for an updated weather data point
- temperature: The temperature of the weather data point (required)
- humidity: The humidity of the weather data point (required)
- pressure: The pressure of the weather data point (required)
- obstacle_detected: Whether an obstacle was detected (required)
- light_intensity: The light intensity of the weather data point (required)

### __Every request returns a JSON file__
- Success: JSON object with a message
- Failure: JSON object with an error message

# Details

### POST request

To create a new weather data point:

```json
{
    "timestamp": "2022-03-07 12:00:00",
    "temperature": 25,
    "humidity": 70,
    "pressure": 1013,
    "obstacle_detected": false,
    "light_intensity": 100
}
```

Response:
```json
{
    "message": "Weather data added successfully."
}
```

### GET request

To retrieve all the weather data points:

Response:

```json
[
  {
    "timestamp": "2022-12-09",
    "temperature": "69420.3",
    "humidity": "45.1",
    "pressure": "1013.2",
    "obstacle_detected": "1",
    "light_intensity": "800.2"
  },
  {
    "timestamp": "2022-12-10",
    "temperature": "69420.3",
    "humidity": "45.1",
    "pressure": "1013.2",
    "obstacle_detected": "1",
    "light_intensity": "800.2"
  }
]
```

### PUT request
To update an existing weather data point:

Request:

```json
{
"timestamp": "2022-03-07 12:00:00",
"new_timestamp": "2022-03-07 13:00:00",
"temperature": 25,
"humidity": 70,
"pressure": 1013,
"obstacle_detected": false,
"light_intensity": 100
}
```

Response:

```json
{
"message": "Weather data updated successfully."
}
```

### DELETE request

To delete an existing weather data point:

Request:

```json
{
"timestamp": "2022-03-07 12:00:00"
}
```

Response:

```json
{
"message": "Weather data deleted successfully."
}
```

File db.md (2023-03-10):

# __Database__
(Reviewed by Luca(not me))
## __Structure__

### __Table: weather_data__

- __timestamp__ (date, primary key): unique identifier for each record</br>
- __temperature__ (float): measured temperature in Celsius</br>
- __humidity__ (float): measured relative humidity in percentage</br>
- __light_intensity__ (float): measured light intensity in Lux</br>
- __pressure__ (float): measured barometric pressure</br>
- __obstacle_detected__ (boolean): Can be used to see if the weather station is covered</br>

---

### __Table: energy_data__

- __timestamp__ (date, primary key): unique identifier for each record</br>
- __battery_level__ (float): current battery level in percentage
- __solar_panel_voltage__ (float): measured solar panel voltage in volts

---

## __ER-diagram__

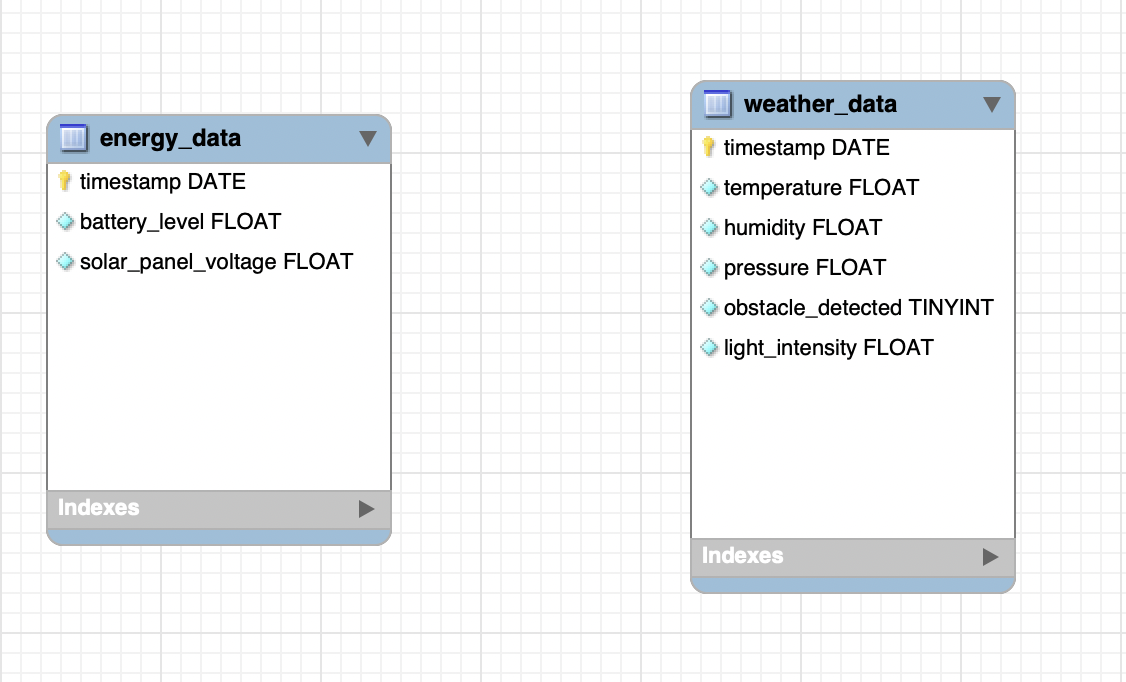
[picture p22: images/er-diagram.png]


//Because appearntly MySQL Workbench is very buggy and old, I can't change some of the column's datatypes

## __ReBuild script__

```sql
DROP TABLE IF EXISTS `WS`.`energy_data`;
DROP TABLE IF EXISTS `WS`.`weather_data`;

CREATE TABLE IF NOT EXISTS `ws`.`energy_data`(
    `timestamp` DATE NOT NULL,
    `battery_level` FLOAT NOT NULL,
    `solar_panel_voltage` FLOAT NOT NULL,
    PRIMARY KEY(`timestamp`)
); 

CREATE TABLE IF NOT EXISTS `ws`.`weather_data`(
    `timestamp` DATE NOT NULL,
    `temperature` FLOAT NOT NULL,
    `humidity` FLOAT NOT NULL,
    `pressure` FLOAT NOT NULL,
    `obstacle_detected` BOOLEAN NOT NULL,
    `light_intensity` FLOAT NOT NULL,
    PRIMARY KEY(`timestamp`)
);
```

__1:__ First connect to your machine and select the database you want to use. 
Execute the SQL script by typing the following command:

``` bash
source /path/to/your/file/create_tables.sql;
```

__2:__ After executing the script, you can check that the tables were created successfully by typing the following command:

```sql
SHOW TABLES;
```

__3.__ You should see three tables: data, energy_data, and weather_data.

## __Insert script__

To add some data to the tables, you can use the following script:

```sql
INSERT INTO `ws`.`energy_data` (`timestamp`, `battery_level`, `solar_panel_voltage`) 
VALUES ('2022-02-01', 0.85, 14.2),
       ('2022-02-02', 0.87, 12.8),
       ('2022-02-03', 0.89, 11.5),
       ('2022-02-04', 0.90, 10.2);

INSERT INTO `ws`.`weather_data` (`timestamp`, `temperature`, `humidity`, `pressure`, `obstacle_detected`, `light_intensity`) 
VALUES ('2022-02-01', 21.5, 65.2, 1015.7, 0, 1024.8),
       ('2022-02-02', 22.1, 61.8, 1016.2, 0, 1025.1),
       ('2022-02-03', 23.0, 57.4, 1016.4, 1, 1025.5),
       ('2022-02-04', 23.5, 54.6, 1016.7, 1, 1025.8);
```

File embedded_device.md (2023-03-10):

# Embedded device

## Hardware overview
### Sensors
- Temperature sensor (KY-001 or KY-013): To measure the ambient temperature.

- Humidity sensor (KY-015): To measure the relative humidity of the air.

- Light sensor (KY-018): To measure the amount of light, which can help determine cloud cover and daylight conditions.

- Obstacle avoidance sensor (KY-032): To detect the presence of physical obstructions, such as rain or snow, which could affect the readings of other sensors.

- Barometric pressure sensor (not included in the list of available sensors): To measure atmospheric pressure, which can help predict weather changes.

### Output devices
- Display (KY-?): To show current temperature.
- LED (KY-?): To indicate the battery level or if the solar panel gets enough energy.

## Connectivity options
- WiFi (ESP???): To connect to the internet and send data to the cloud.
- LoRa (not included in the list of available sensors): To send data to the cloud.

## Energy management
- Solar panel (KY-?): To charge the battery.
- Battery (KY-?): To store energy.

- A charge controller is required to control the charging and discharging of the batteries
  
- The charge controller regulates the flow of current from the solar panel to the battery to ensure that the battery is not overcharged or discharged.

- During the day, the solar module charges the battery via the charge controller.

- At night or when there is little sunlight, the battery supplies power to the weather station via the charge controller.

## Information for myself

Der Wemos Lolin D1 ist ein kleines, kostengünstiges Entwicklungsboard, das mit der Arduino IDE kompatibel ist und für die Entwicklung von Internet of Things (IoT)-Projekten konzipiert wurde. Das Board basiert auf dem ESP8266-Mikrocontroller und bietet eine Reihe von Konnektivitätsoptionen, einschließlich Wi-Fi und Bluetooth.

Hier ist ein kurzer Überblick über einige wichtige Pins auf dem Wemos Lolin D1:

TX/RX: Dies sind die Pins, die für die serielle Kommunikation verwendet werden. TX steht für Senden und RX steht für Empfangen.
SCL/SDA: Dies sind die Pins für die I2C-Kommunikation, ein Zweidraht-Kommunikationsprotokoll, das zum Anschluss mehrerer Geräte an einen einzigen Mikrocontroller verwendet wird.
GND: Dieser Pin ist die Masseverbindung für die Platine und wird zum Abschließen elektrischer Schaltungen verwendet.
VBUS: Dieser Pin wird zur Stromversorgung externer Geräte verwendet, die an die Platine angeschlossen sind.
RST: Dieser Pin wird zum Zurücksetzen der Platine verwendet.
Ruhezustand: Dieser Pin wird verwendet, um die Karte in den Sleep-Modus zu versetzen, einen Energiesparmodus, der zur Verlängerung der Batterielebensdauer nützlich sein kann.
SCK/MISO/MOSI/SS: Diese Pins werden für die SPI-Kommunikation verwendet, ein Vier-Draht-Kommunikationsprotokoll, mit dem mehrere Geräte an einen einzigen Mikrocontroller angeschlossen werden können. SCK steht für den seriellen Takt, MISO steht für Master-Input-Slave-Output, MOSI steht für Master-Output-Slave-Input und SS steht für Slave Select.
3v3: Dieser Pin ist die 3,3-V-Stromversorgung für die Platine und wird zur Versorgung externer Geräte verwendet, die an die Platine angeschlossen sind.

## Wiring diagram

## Bill of Materials

## Links

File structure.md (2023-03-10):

# IOT HVA

# Course Info

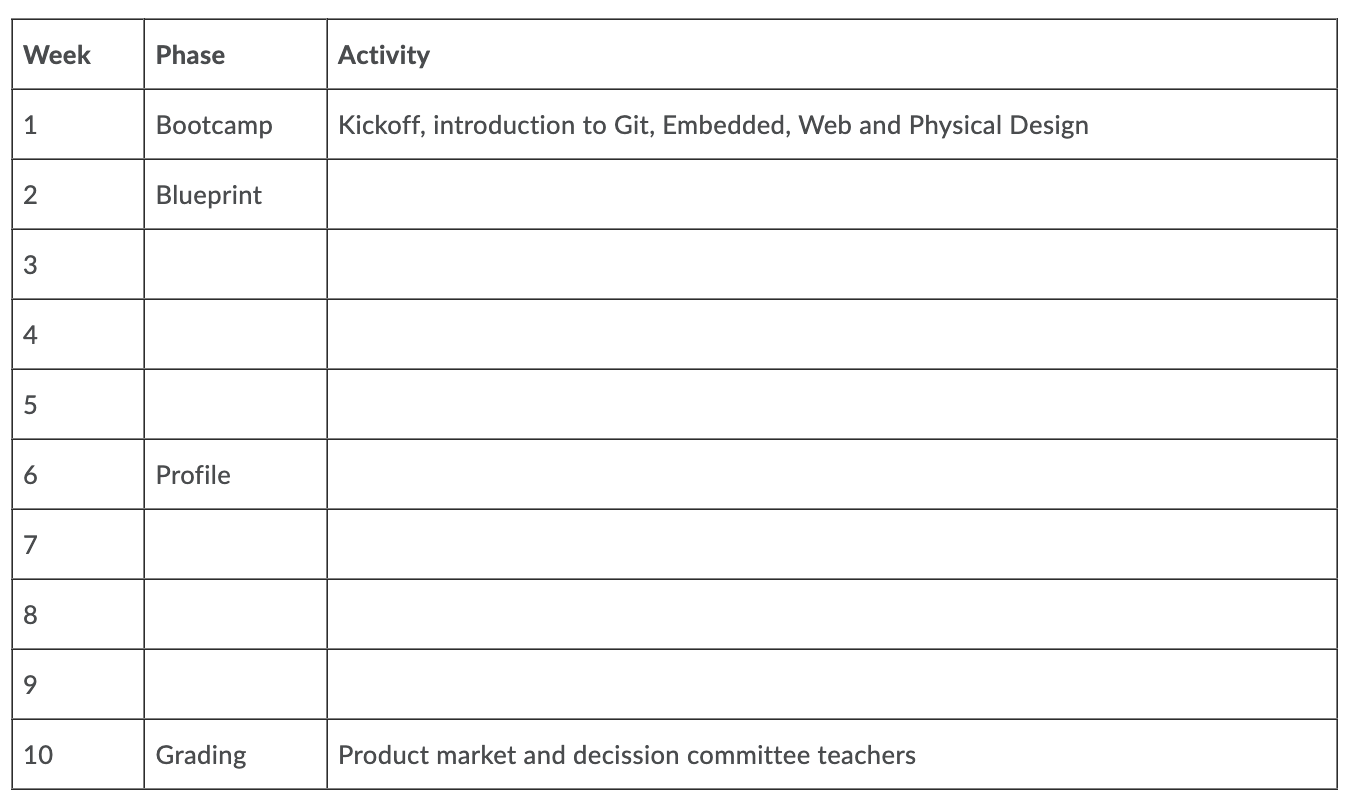
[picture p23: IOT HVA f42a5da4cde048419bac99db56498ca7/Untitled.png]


## Website

[](https://dlo.mijnhva.nl/d2l/le/lessons/471080/lessons/1556473)

- Bewertet basierend auf Verbesserung und Erwartungen
- Konsistens ist key
- Basiert auf verschiedenen Kategorien: web, itsec, embedded, business, ui
- Alles muss im Portfolio mit Markdown sein
- Update portfolio weekly
- mysql workbench

## Blueprint structure and requirements

### Infos

[weather-station.html](IOT%20HVA%20f42a5da4cde048419bac99db56498ca7/weather-station.html)

### Project organisation

- Connection between Notion and Markdown Gitlab server?!? → https://github.com/souvikinator/notion-to-md bash script which uploads daily an updated version of my notion as markdown to the documentation (bash script or command alias)
- Issue managment?
- Can be developed in Github as fork and later merge it
- Should everything be done at the same time? because weekly commits are wanted or is that because we use the gitlab documentation
- Are there example repo’s?

### Timeline

- ************************************************************************Basic should be finished in 3 weeks************************************************************************
- First get arduino with minimum sensors running
- Build Backend to fetch from client
- Build and design 3D chasis (Because website can be done at home)
- Create website to display data from backend

### Backend

- Docker container with NGINX and MySQL
- User authentication
- Endpoints
- Security:
    - Https
    - SSL?
    - User login
    - Encryption → Check with ChatGPT for Algos and Architecture
- Punktevergabe Backend
    
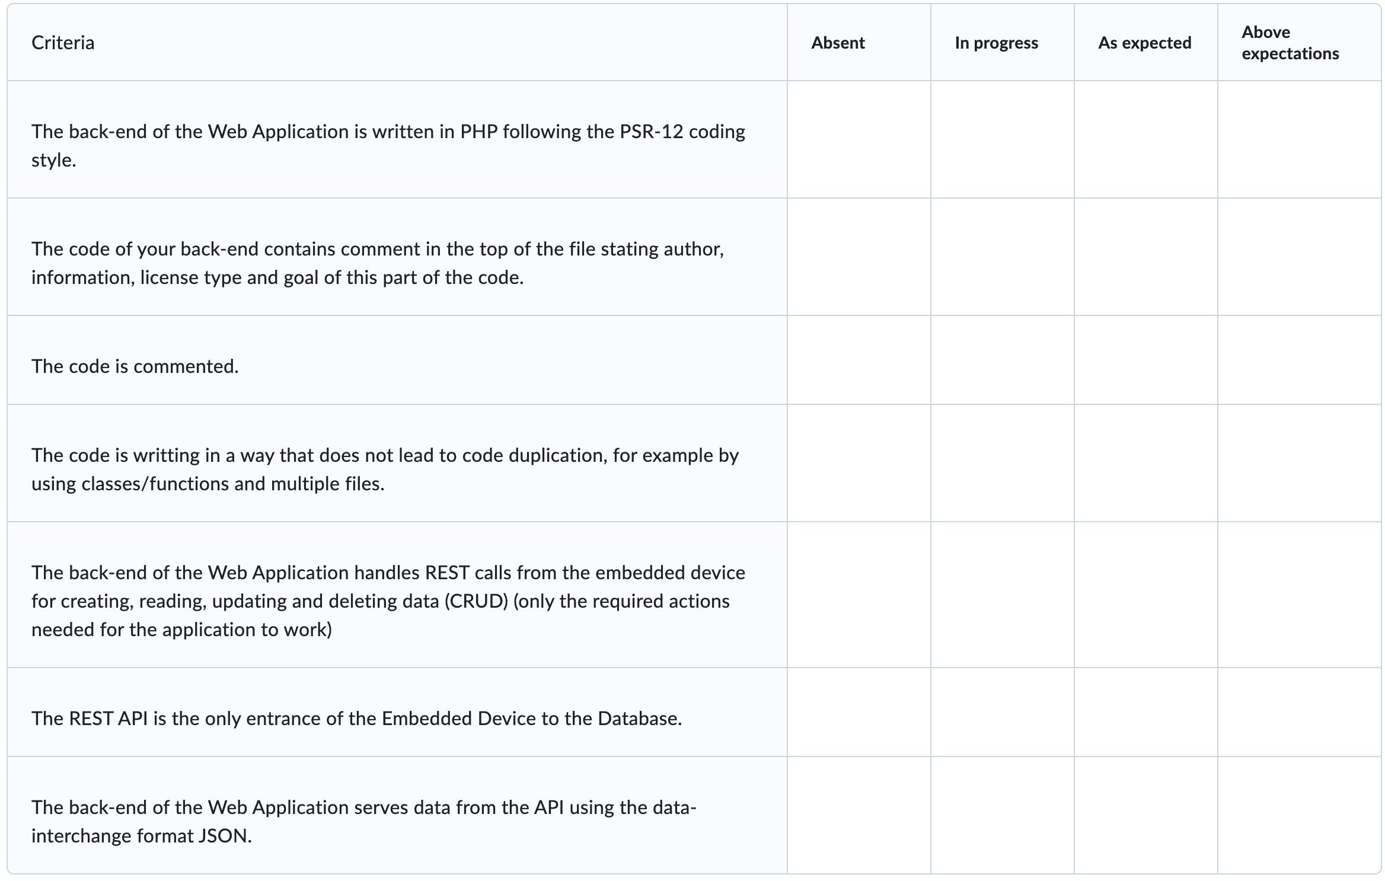
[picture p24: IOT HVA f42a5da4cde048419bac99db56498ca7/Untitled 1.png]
    
    
- Punktevergabe Database
    
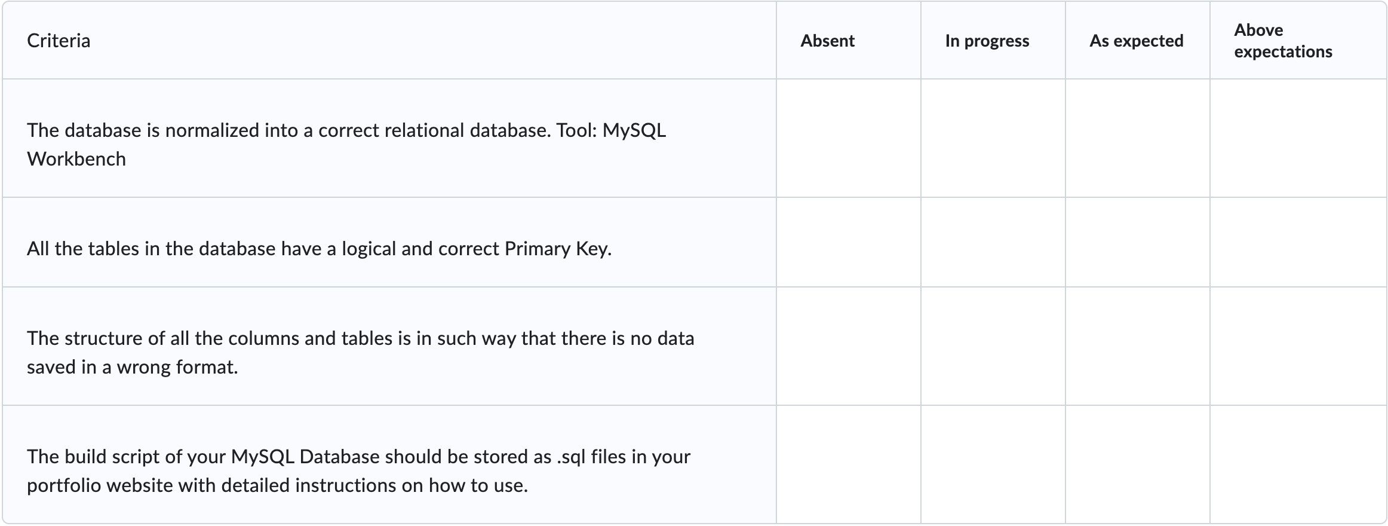
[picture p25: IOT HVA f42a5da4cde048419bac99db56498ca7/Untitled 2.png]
    

### Frontend

- No inline stuff
- Tailwind css??
- Displaying values with → **Chart.js**
- AJAX
- Punktevergabe Frontend
    
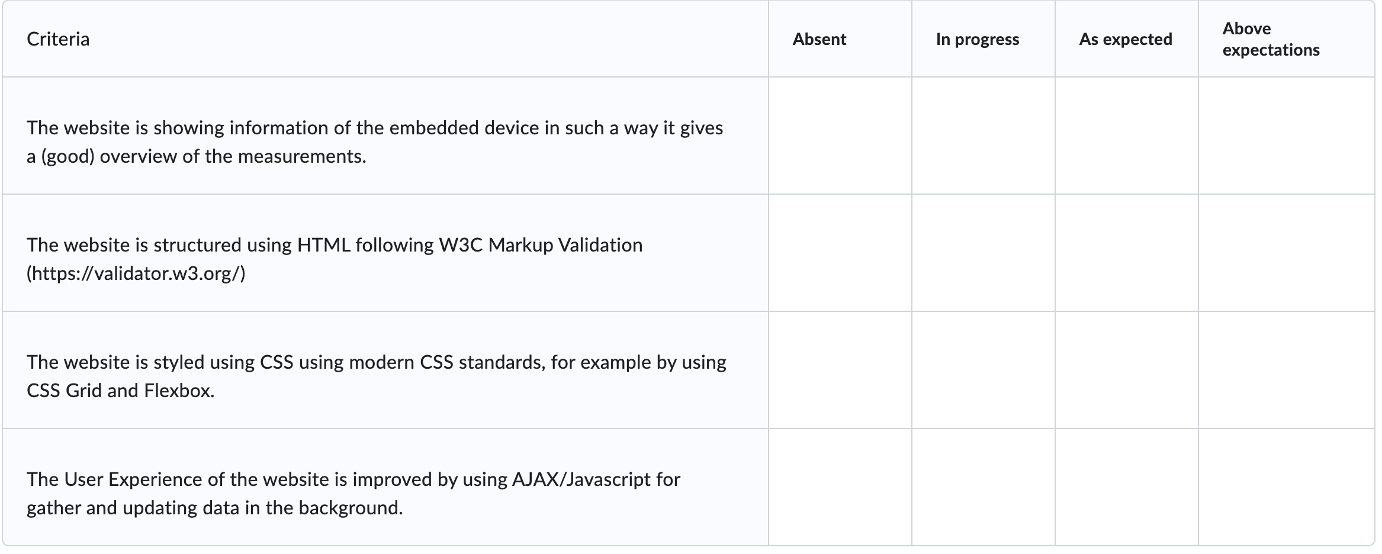
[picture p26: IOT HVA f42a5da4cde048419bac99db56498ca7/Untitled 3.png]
    

### Embedded

- Structure in Fritzing
- Input Sensonrs
    - Temperature
    - Wind?
    - Humidity
- Output
    - Display for basic information → details on website
    - Speaker for battery problems
- Solar and Wind powered
- LoRa?
- Where are the criterias ?!?!?

### Physical Design

- 3d printed modular casing to allow more expansions later
    - each sensor one module (or similar sensors one module)
    - standardized mounting points
    - central mounting bar (tree structure)
- Or pipe system

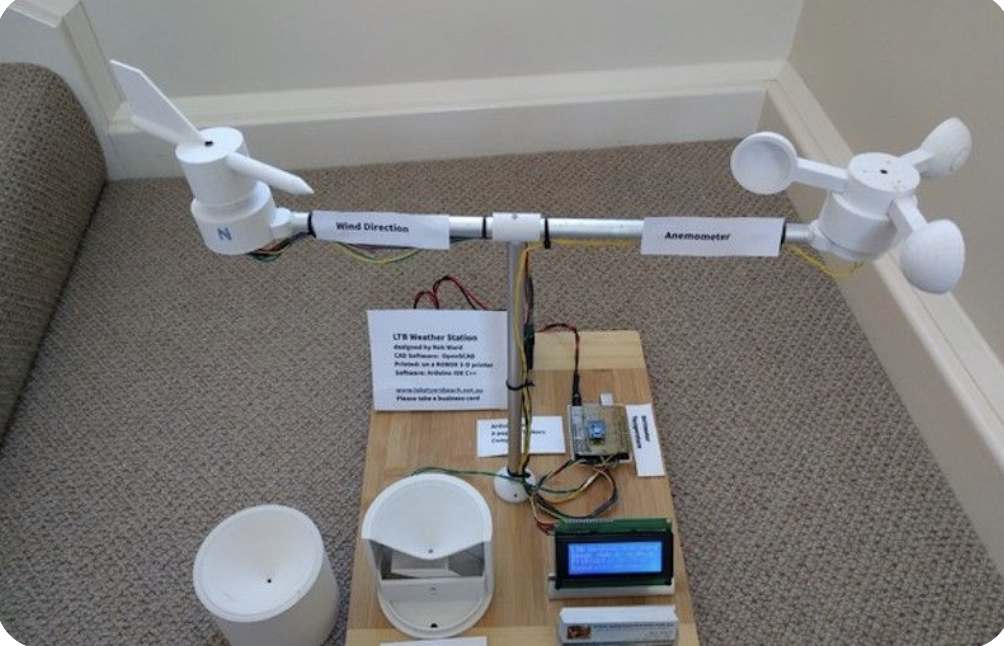
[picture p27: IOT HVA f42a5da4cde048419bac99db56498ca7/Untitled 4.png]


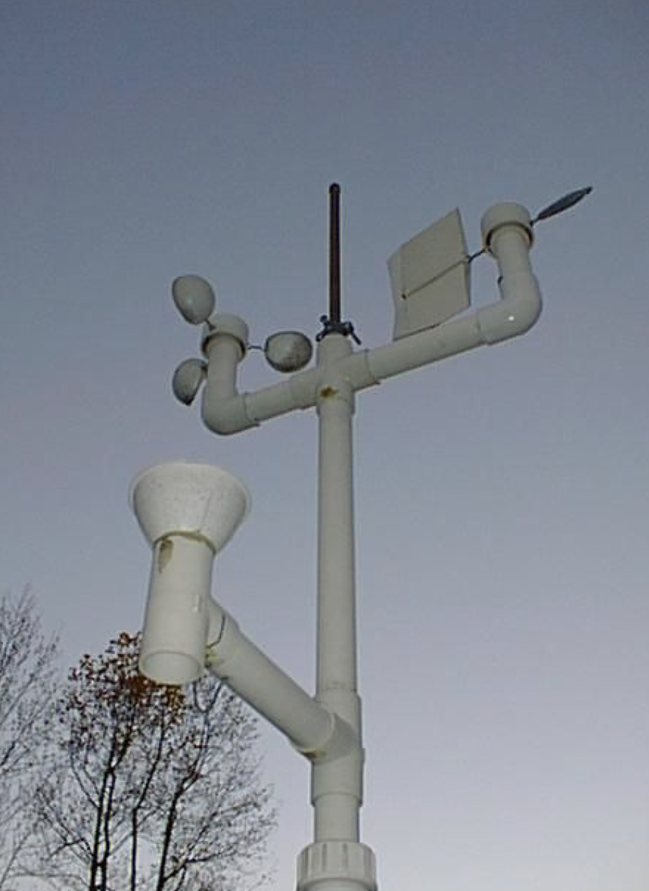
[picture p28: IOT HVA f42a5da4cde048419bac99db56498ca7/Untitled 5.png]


- Punktevergabe Design
    
    
    
    
    
    
    
- Punktevergabe Create
    
    
    
    
    
    
    
- Punktevergabe Failures
    


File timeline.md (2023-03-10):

## Timeline
- On the 20. February I tried to connect the DHT and the display -> I got the DHT working after some time but the display didn't work. I tried to connect the display to the D1 mini and the Arduino Uno but it didn't work. One of the tutors said its broken.
  
- On the 21. February, I successfully all sensors I want to use to the Wemos(DHT11, Phtoresistor, LCD-Display and red led to display some useful information). All sensors are working, but I have to change the code to connect them to my backend.


- On the 22. February, I connected the wemos to the wifi manager, restructed the database once again and made a concept for the physical design of the weather station. I also started to work on the backend and the frontend.

- On the 23. February, I started to work on the backend and the frontend. Since I have no experince with PHP, I had to learn it first. I also started to work on the frontend. 

- After the break, I started on the 6. March to work on the backend and the frontend. The frontend should be finished. I can display data from the backend with ajax and is able to plot the data in four different graphs. Image will follow in the detailed assignment. The backend is now able to access datafrom the database and use it to add entries and to display them. I also started to work on the physical design of the weather station. I made the first draft print of the final version it is printing tonight.

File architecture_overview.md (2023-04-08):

# Architecture overview

The architecture of the system is shown in the following diagram:

dia

Please note the shapes do not represent actual classes or objects, but rather the different components of the system.

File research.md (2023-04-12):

# How can Golang be used to implement a better backend for Weather Wizard?

In the first version of Weather Wizard, we used PHP for the backend. PHP is very popular, has great community support,
is used in a lot of projects and is easy to learn. However, there are more modern languages which are coming up and
offer
plenty of benefits over old languages. One of those languages is Go.

Go, often referred to as Golang, is an open-source programming language that was developed by Google in 2009.
Go is gaining a lot of popularity in the last years and has become one of the most popular languages for backend
development. The language's philosophy is to be simple, fast, and efficient.

## For whom is this research relevant?

The target audience for this research are developers and engineers who are interested in using Golang for backend
development in small scale or personal projects.

## What are methods and sources to research this question?

To narrow down the research question, I will focus on the following topics:

- What are the benefits of developing in Golang?
- What libraries and technologies can be used for backend development in Golang?
- What is the best architecture for a Weather Wizard backend in Golang?

These topics will be researched by reading articles and developer blogs, watching videos and tutorials, and by analyzing
surveys and benchmarks.

## What are the benefits of developing in Golang?

Many features of Go make it a great choice for backend development. Go is a compiled language, which means that it is
actually
converted to binary before it is executed on a machine
This makes it a lot faster than other languages which use an interpreter (Etienne, 2022). Another great feature of
Golang is its Garbage
Collector. The Garbage Collector makes it much easier to
manage memory in Go. Most other compiled languages require you to manually manage your memory, which can be a lot of
work and is very error-prone (Etienne, 2022). Microsoft estimated that 70% of all security breaches are caused by bad
memory
management (2019).
Furthermore, Go is a statically typed language, which means that you have to define the type of variable when you
declare it, which makes it a lot easier to
find errors in your code before
runtime and also increases the speed of execution (Instil, 2019).
The easy syntax of Go also makes it a lot easier to learn than other languages.
The syntax of Go
is very similar to C, which makes it easy to switch language (Etienne, 2022). The last feature that I want to
mention is the concurrency of Go.
Golang has very good support for concurrency. That means that you run multiple threads and processes at the same time,
which is very useful for backend development,
since it allows you to handle many requests and perform multiple tasks simultaneously, what improves performance and
responsiveness (Etienne, 2022).

For all those reasons, many companies have switched to Golang for their backend development. Here are some examples:

- Uber: Uber heavily relies on Golang for backend development, notably its dispatch system and map services. Uber can
  handle a huge number of requests concurrently thanks to Golang's concurrency characteristics, making it simpler to
  deliver a smooth experience for its consumers (Uber Blog, 2019).

- Dropbox: Dropbox's desktop client, which manages file syncing between devices, is written in Golang. The desktop
  client can sync data rapidly and effectively thanks to Golang's fast execution speeds and concurrency
  characteristics (Lee, n.d.).

- Docker: Docker uses Golang to implement its core container runtime, as well as various other components such as the
  Docker CLI and Docker Compose (Docker and Go, n.d.)

And there are many more examples, like Netflix, Meta, Cloudflare and of course Google itself. Most developer teams have
said that they switched to Golang because of its performance and concurrency characteristics (Case Studies - the Go
Programming Language, n.d.).

### Drawbacks of Golang

Even though Golang has many great features, it also has some drawbacks.

- Lack of Generics: Golang lacks the functionality of Generics. This can limit developers in some use cases, because
  Generics allow you very easily to
  create reusable code.

- A smaller standard library compared to other programming languages: Golang has a standard library, but it is fairly
  small compared to other programming languages that have had years to establish a big ecosystem of libraries. Thus, to
  complete certain tasks, programmers often need to employ libraries of third party sources.

- Unique Syntax: Some developers can find the syntax of Golang a bit strange and find that it feels very unfamiliar.

## What libraries and technologies can be used for backend development in Golang?

Since Golang is very popular for backend development, there are also a lot of libraries available for it.

To get familiar with good libraries which are offered in the Golang ecosystem, I can recommend the following Github
page: https://github.com/avelino/awesome-go

It contains a list of the most popular libraries and frameworks for Golang. It is structured by category, so it is easy
to find the right library for your use cases. It is also very well maintained and updated frequently.

https://madappgang.com/blog/backend-development-with-golang/

For weather wizard, we need the following types of libraries and technologies to build a modern backend:

#### Database:

Since we already worked with MySQL, it makes sense to use another sql database. I decided to pick PostgreSQL, because
it is a very popular and modern database. It has a lot of features that make it objectively better than MySQL (Ravoof,
2023).
Of course, it is also open-source and free to use. The Stack Overflow developer survey 2022 shows that PostgreSQL is the
most popular
database under professional developers (2022). It is also the most
popular database for backend development.



Nevertheless, there is not a big one decisive reason why I should pick one of the popular sql databases over the others
Almost all popular sql databases, which are not deprecated, are very good and have a lot of features.

NoSQL databases on the other hand would require us to change our whole data model, which is not worth the effort.

https://github.com/mingrammer/go-web-framework-stars

#### Web-framework:

The most popular and most used web-framework for Golang is currently Gin, but after doing some research I decided to
pick Fiber. Fiber is a better choice than Gin due to its better performance, nicer syntax, and more comprehensive
documentation (Coding with Robby, 2022). The strong performance is also shown in the TechEmpower benchmarks (n.d.). The
benchmark consists of three parts.

1. Database access: The test demands the web application to connect to a database, get records, and execute specified
   operations on the data.

2. Server-side templating: After retrieving records from the database, the web application must generate an HTML view
   using server-side templates. This tests the framework's ability to handle dynamic HTML creation.

3. JSON serialization: The test requires the web application to serialize data into JSON format, which tests the
   framework's JSON handling skills.

benchmark

Fiber is the third fastest web-framework for Golang, with only rather small and less popular frameworks being faster.
It is also the 24. fastest web-framework for all languages. Gin is only the 162. fastest web-framework.
For me, it was also easier to get started with Fiber, because I was already familiar Express.js, which is a similar
web-framework for Node.js.

#### ORM (Object Relational Mapping):

ORM is a technique that allows you to query and manipulate data from a database using an object-oriented paradigm.
Using an ORM allows developers to leverage their fluency in a programming language, simplifying database interactions
and abstracting away SQL complexities (Hoyos, 2023). It offers easy database system switching, advanced built-in
features, and often
leads to better-performing queries than handwritten SQL. It is typically recommended for small projects, to make rapid
development easier.

#### Monitoring and Logging and Notification:

For monitoring, the most popular frameworks are Prometheus and Grafana. Both are open-source and free to use. You can
deploy them in a docker container and connect them to your application.
After setting them up, you can see the performance of your application in real-time like here:

grafana
Logging is really important to debug your systems and to know what is happening in the black box of your application (
Isaiah, 2022).

For logging, a logging framework doesn't have to be used for a small scale project like Weather Wizard. The standard
library of Golang already provides a good logging framework.

For bigger projects, it is recommended to use a proper logging framework. The most popular and widely used logging
framework is called Logrus (Gartner, 2022).

Logrus supports a variety of output formats, log levels, and hooks, as well as structured logging. Its adaptability and
extensibility make it an excellent choice for a wide range of applications.

Grafana, Prometheus, as well as a different notification system, are both capable of implementing notifications. Email,
Slack, Telegram, and other messaging systems are all capable of implementing the notifications.

Because setting up a mail server is not necessary, I choose to use an email provider for the alerts. SendGrid is the
easiest and feature richest email provider that also allows for Golang programming (Wagner, 2021). It is also quite
simple to start up and gives a
free tier with 100 free emails each day.

### Authentication

For authentication, the most popular modern token based authentication is JWT. JSON Web Tokens (JWTs) are a widely used
standard for securely exchanging data between parties (Kumar, 2022). JSON Web Tokens are often used to authenticate
users and prove
authorization information and consist of a header, payload, and signature. JWTs are adaptable and simple to implement,
and they can be
used in a broad range of applications and use situations. Although for a small scale project like Weather Wizard, a more
simplistic authentication method can also be used. Basic authentication is a simple authentication scheme built into the
HTTP protocol. The client sends HTTP requests with the Authorization header that contains the word Basic word followed by a space and a base64-encoded string username:password.
The server decodes the base64 string, splits the string into the username and password components, and
verifies that the given credentials are valid. Basic authentication may not be very feature rich, but it is very easy to
implement and use (HTTP Authentication - HTTP | MDN, 2023). It also doesn't require any additional libraries. Its only
draw is that it doesn't offer confidentiality, so
the password is sent in plain text, but this can be mitigated by using HTTPS instead of HTTP.

The implementation of Basic authentication looks like this:

basic auth

### Testing:

The most popular testing framework for Golang is Testify, but most Golang developers stated in the JetBrains survey,
that they prefer the standard library of Golang for testing.
Altogether, the standard library of Golang is very good and provides all the necessary tools for testing (Go
Programming - the State of Developer Ecosystem in 2022 Infographic, n.d.). It is also
very easy to use and has a great documentation.
Testify can be used if more advanced features are needed, but for a small scale project, the standard library is sufficient.
Testify has a lot of features like mocking, assertions, and test suites.

## What is the best architecture for a Weather Wizard backend in Golang?

You should choose the architectural pattern before you create a new backend. For this project, there are primarily
two architectural patterns that matter. The monolithic architecture is the first, while the architecture of
microservices is the second.

### Microservices' architecture:

An application is separated into smaller, independent services that may interact with one another through APIs in a
microservice architecture. This approach facilitates deployment and maintenance while improving scalability,
flexibility, and fault separation (Atlassian, n.d.). Nevertheless, it may lead to increased complexity and
administrative burden, more
expensive infrastructure and operational costs, and more difficult end-to-end functionality testing.

### Monolithic architecture:

Monolithic architecture is an architectural style in which an application is constructed as a single united system.
This technique encourages simplicity, quicker development and testing, and improved speed (Atlassian, n.d.).
Nevertheless, it limits scalability and flexibility. It also provides limited support for polyglot development, which
allows various programming
languages and technologies to be utilized for different areas of the application.

### Which architecture pattern should be used for what project?

A monolithic architecture is a better choice for a small-scale project than a microservice design. A monolithic
design is quicker to construct and administer, needs less infrastructure resources, and is easier to verify end-to-end
functionality (Atlassian, n.d.).

Microservice architecture, on the other hand, is more complicated and necessitates more infrastructure resources. It is
often better suited for bigger and more complicated applications that require high scalability, fault tolerance, and
autonomous service deployment (Atlassian, n.d.).

Nevertheless, the particular objectives and constraints of the project ultimately decide between monolithic and
microservice design. If the project is projected to grow significantly in the future or if it requires independent
scaling and deployment of various services, microservice architecture may be a better option. On the other hand, if the
project is anticipated to have a lower scope and scale or if simplicity and convenience of development and management
are the primary criteria, a monolithic design could be more suited.

## How could such an implementation look like?

The most widely used standard for APIs in a monolith architecture is REST.

The REST API (Representational State Transfer) is a web-based software architecture approach for developing scalable and
adaptable distributed systems. A RESTful API enables customers to access and alter resources over HTTP using established
methods (What Is a REST API? | IBM, n.d.).

Clients should be able to conduct conventional CRUD (Create, Read, Update, Delete) activities on resources defined by
URIs via a REST API (Uniform Resource Identifiers). The API should use a stateless communication paradigm, in which the
server does not save the client's state, and each request provides all the information needed to process it.

#### Why should be a REST API be used?

- Defines a common language for numerous systems, simplifying development.
- Is another abstraction layer that simplifies technological changes.
- REST is the most prevalent API architecture, therefore documentation and tools are abundant.
- The API is lighter and interoperable with many communication formats.
- Automated ETL and data integration may leverage REST APIs.

(Smallcombe, 2021)

## Conclusion

To summarize, Golang is an excellent alternative for creating high-performance, scalable, and concurrent applications.
Because of its compiled nature, garbage collector, static typing, easy syntax, and high concurrency support, it is a
popular choice for backend development. Organizations like Uber, Dropbox, and Docker have turned to Golang for backend
development, citing its high speed and parallelism.

I propose PostgreSQL as the database, Fiber as the web framework, and GORM as the ORM for Weather Wizard. I suggest
Prometheus or Grafana for monitoring. Basic HTTP Authentication can be used to provide a basic layer of security.
The basic Golang library is adequate for testing, while Testify can be used for more sophisticated capabilities. To
notify
an administrator about errors and logs, I recommend using SendGrid's API.

In terms of architecture, whether to utilize a monolithic or microservice architecture ultimately relies on the
project's unique aims and restrictions. A monolithic design may be more suitable for a small-scale project, but a
microservice architecture may be better suited for larger and more complex systems that require great scalability and
fault tolerance. Due to the size of the project, I would recommend a monolithic architecture.

Lastly, a REST API should be utilized for the backend because it is a widely used and standardized way for constructing
scalable and adaptive distributed systems. It simplifies development, offers technological advantages, and may be
utilized for a wide range of applications.

## Recommendations

| Stack | Recommendation | URL |
|---|---:|---|
| Language | Golang | https://go.dev/ |
| Database | Postgres | https://www.postgresql.org/ |
| Web-framework | Fiber | https://gofiber.io/ |
| ORM | Gorm | https://gorm.io/ |
| Monitoring | Grafana / Prometheus | https://grafana.com/ / https://prometheus.io/ |
| Logging | Standard Logger | https://pkg.go.dev/log |
| Notifications | Sendgrid | https://sendgrid.com/ |
| Architecture  | Monolith REST API | https://www.integrate.io/blog/why-you-need-a-rest-api/ |

## References

- A. (n.d.-a). GitHub - avelino/awesome-go: A curated list of awesome Go frameworks, libraries and software.
  GitHub. https://github.com/avelino/awesome-go
- Atlassian. (n.d.). Microservices vs. monolithic architecture |
  Atlassian. https://www.atlassian.com/microservices/microservices-architecture/microservices-vs-monolith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,monolith%20architecture%20for%20software%20design
- Case Studies - The Go Programming Language. (n.d.). https://go.dev/solutions/case-studies
- Coding with Robby. (2022, October 11). Is Fiber the best Go web framework? Better than Gin? [Video].
  YouTube. https://www.youtube.com/watch?v=10miByMOGfY
- Docker and Go: why did we decide to write Docker in Go? | Hacker News. (
  n.d.). https://news.ycombinator.com/item?id=6709517
- Etienne, J. (2022, April 23). Why Go: The benefits of Golang - Julien Etienne - Medium.
  Medium. https://medium.com/@julienetienne/why-go-the-benefits-of-golang-6c39ea6cff7e
- Gartner, M. (2022, April 2). Awesome Logging in Go With Logrus - Better Programming.
  Medium. https://betterprogramming.pub/awesome-logging-in-go-with-logrus-70606a49f285
- Go in 2018 - The State of Developer Ecosystem by JetBrains. (n.d.).
  JetBrains. https://www.jetbrains.com/research/devecosystem-2018/go/
- Go Programming - The State of Developer Ecosystem in 2022 Infographic. (n.d.). JetBrains: Developer Tools for
  Professionals and Teams. https://www.jetbrains.com/lp/devecosystem-2022/go/
- Hoyos, M. (2023, March 22). What is an ORM and Why You Should Use it - Bits and Pieces.
  Medium. https://blog.bitsrc.io/what-is-an-orm-and-why-you-should-use-it-b2b6f75f5e2a
- HTTP authentication - HTTP | MDN. (2023, March 3). https://developer.mozilla.org/en-US/docs/Web/HTTP/Authentication
- Introducing AresDB: Uber’s GPU-Powered Open Source, Real-time Analytics Engine | Uber Blog. (2019, January 29). Uber
  Blog. https://www.uber.com/en-NL/blog/aresdb/
- Isaiah, A. (2022, December 20). 6 Factors to Consider When Choosing a Logging Framework. Better Stack
  Community. https://betterstack.com/community/guides/logging/logging-framework/
- Kumar, S. (2022, April 25). How JWT (JSON Web Token) authentication works? DEV
  Community. https://dev.to/kcdchennai/how-jwt-json-web-token-authentication-works-21e7
- Lee, P. (n.d.). Open Sourcing Our Go Libraries.
  Dropbox. https://dropbox.tech/infrastructure/open-sourcing-our-go-libraries
- M. (n.d.-b). GitHub - mingrammer/go-web-framework-stars: Web frameworks for Go, most starred on GitHub.
  GitHub. https://github.com/mingrammer/go-web-framework-stars
- M. (2019, July 16). A proactive approach to more secure code | MSRC Blog | Microsoft Security Response
  Center. https://msrc.microsoft.com/blog/2019/07/a-proactive-approach-to-more-secure-code/
- Ravoof, S. (2023, February 17). PostgreSQL vs MySQL: Explore Their 12 Critical Differences.
  Kinsta®. https://kinsta.com/blog/postgresql-vs-mysql/#:~:text=MySQL%20is%20a%20purely%20relational,%2C%20ACID%2Dcompliant%20storage%20engine.
- S. (n.d.-d). GitHub - sirupsen/logrus: Structured, pluggable logging for Go.
  GitHub. https://github.com/sirupsen/logrus
- Smallcombe, M. (2021, August 3). Why You Need a REST API.
  Integrate.io. https://www.integrate.io/blog/why-you-need-a-rest-api/
- Stack Overflow Developer Survey 2022. (n.d.). Stack Overflow. https://survey.stackoverflow.co/2022/
- Static Types vs Dynamic Types. Stop fighting and make my life easier already | Instil. (n.d.). Insights by
  Instil. https://instil.co/blog/static-vs-dynamic-types/#:~:text=Protection%20from%20Runtime%20Errors,a%20much%20smoother%20development%20experience
- TechEmpower Framework Benchmarks. (n.d.). https://www.techempower.com/benchmarks/#section=data-r21&test=fortune
- Wagner, J. (2021, July 7). Top 10 Best Email APIs. Rapid
  Blog. https://rapidapi.com/blog/email-apis-which-one-is-right-for-you/
- Web and mobile app development company. (n.d.). https://madappgang.com/blog/backend-development-with-golang/
- What is a REST API? | IBM. (n.d.). https://www.ibm.com/topics/rest-apis

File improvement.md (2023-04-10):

# Improvements

My research focused on the backend of Weather Wizard. I wanted to implement the best possible backend in the given
timeframe. In the
following I will explain the improvements I made.

I'm using Golang language for the backend of Weather Wizard. before talking about the implementation of the backend, I
will explain the language itself.
Golang is a compiled language, which means that the code is compiled to machine code before it is executed. This makes
it much faster than interpreted languages like PHP.
Golang is also a statically typed language, which means that you have to define the type of variable when you declare
it. This makes it easier to find bugs in your code.
It is also garbage collected language like Java, which means that you don't have to worry about memory management like
in C or C++. The garbage collector will clean up after you.
Furthermore, Golang is a concurrent language, which means that you can run multiple threads at the same time. This is
very useful for web development, since you can run multiple
requests at the same time. It is language that is very easy to learn and has a lot of useful features. This makes it a
very popular language for backend development and also the reason
why I wanted to learn it.

Because Golang is a very popular language for backend development, there are a lot of libraries available for backend
development. I used the following libraries for this project.

## Libraries

These are the rather regular libraries that I used for this project, which don't need much explanation:

- encoding/json: Functions for encoding and decoding JSON data.
- fmt: Formatted I/O functions for I/O and string-based operations.
- log: A straightforward logging package with basic logging features.
- net/url: Methods for modifying URL components and parsing URLs.
- encoding/base64: Helps to convert data into base64 format and vice versa.
- io/ioutil: Functions for basic I/O utility activities like reading and writing files.
- os and path/filepath: Tools for working with the file system and operating system, including file manipulation.
- Regexp: Regular expression working functions.
- time: Time, durations, and date-related functions.

These are the libraries that are a bit more important for this project:

- Fiber: A fast, simple, and minimalist web framework for Go.
- Gorm: An ORM library for Golang. It helps to work with databases, specifically PostgreSQL.
- fatih/color: Makes it easy to add colors to text in the console.
- sync: Helps to coordinate tasks and protect shared resources.
- Sendgrid: A library for sending emails.
- fatih/color: Makes it easy to add colors to text in the console.

Next to these libraries, I also used the following other technologies:

- PostgreSQL: A relational database management system setup in a docker container.
- Docker: A container platform.
- Docker-compose: A tool for defining and running multi-container Docker applications.
- Sendgrid: A service for sending emails.
- Air: A live reload tool for Go applications.
- Grafana: A tool for visualizing data.
- Insomnia: A tool for testing tool for http, websockets and graphql requests.

Why I picked them specifically is stated in the research assignment.

## Foundation

Before I get started with the documentation of the backend, I recommend checking out the [Architecture overview](./architecture_overview.md).
The documentation of the backend is very long, and the architecture overview shows the big picture of the backend.

Since I also added around 1000 lines of code, I will only focus on the most important parts of the source code and not too
much on language specific
details. The starting point of the backend is the main file and its main function as you might know it from
Java or C#.

First, there are two global objects declared, which are the dbManager and the fiberApp. They get initialized in the
initBackend function and
are created with the New functions The new functions is similar to the constructor in Java or C#. It returns a new
object of the given type and also initializes it.
The DBManager in this case is initialized with the NewDBManager function. This function takes 2 parameters, the database
type and the connection string.
The fiberApp is initialized with a separate function. This is because the fiberApp now listens for requests and is
blocking the main thread.

```go
package main

var dbManager *DBManager
var fiberApp *FiberApp

func main() {
	initBackend()
}

func initBackend() {
	//new db manager object
	dbManager = NewDBManager("Postgres", "host=localhost port=5432 user=postgres password=postgres dbname=postgres sslmode=disable")
	dbManager.GetInfo()
	dbManager.setupDb()

	//new fiber app object
	fiberApp = NewFiberApp()
	fiberApp.InitFiber() //This must be the last thing since it starts the server
}
```

I will continue next with the DBManager. This is an important part of the backend, since it is responsible for all
database related tasks.
This Function is creating a new DBManager object and also initializes it. It takes 2 parameters, the database type and
the connection string.
It sets up the postgres database connection with the gorm library.

```go
func NewDBManager(name string, dsn string) *DBManager {
var d = DBManager{db: nil, name: name, insertSql: "insert.sql", rebuildSql: "rebuild.sql"}

var err error
d.db, err = gorm.Open(postgres.Open(dsn), &gorm.Config{})
if err != nil {
d.LogError("Failed to connect database")
}

d.Log("Connected to database")

return &d
}
```

This is the struct of the object. It contains the database connection, the name of the database, the paths of the sql
insert and rebuild files.

```go
type DBManager struct {
db         *gorm.DB
name       string
insertSql  string
rebuildSql string
}
```

The function called afterward is the GetInfo function. This function returns information about the DBManager. This
function is only used to ensure that the DBManager is initialised correctly.

```go
func (d *DBManager) GetInfo() {
d.Log(fmt.Sprintf("%+v", d))
}
```

It is one of many utility functions, getters, and setters that I added to the DBManager and the fiberAPP to make it
easier to develop and debug the backend. These are some of them, which both the DBManager and the fiberApp have:

```go

func (d *DBManager) SetDBManager(db *gorm.DB, name string) {
d.SetName(name)
d.SetDB(db)
}

func (d *DBManager) SetDB(db *gorm.DB) {
d.db = db
}

func (d *DBManager) SetName(name string) {
d.name = name
}

func (d *DBManager) GetDB() *gorm.DB {
return d.db
}

func (d *DBManager) GetName() string {
return d.name
}

func (d *DBManager) ToString() string {
return fmt.Sprintf("Running %s ", d.name)
}
```

But there is also other functionality which I will not explain more detailed. Most of them have functionality that are
not very relevant for the project itself, but make extension, debugging and testing much better:

_Logs all the weather data from the database to the console_

```go
func (d *DBManager) logWeatherData() {
// Initialize a slice of maps to store the weather data
var data []map[string]interface{}

// Find the weather data from the "weather_data" table
result := d.db.Table("weather_data").Find(&data)

// Check if there was an error while finding the data
if result.Error != nil {
// Log the error message
d.Log(result.Error.Error())
return
}

// Check if no rows were affected (i.e. no data was found)
if result.RowsAffected == 0 {
// Log a message indicating that no data was found
d.Log("No weather data found")
return
}

// Loop through the data and log each item as a JSON string
for _, item := range data {
// Convert the map to a JSON string
jsonString, err := json.Marshal(item)

// Check if there was an error while converting to JSON
if err != nil {
// Log the error message
d.Log(err.Error())
continue
}

// Log the JSON string
d.Log(string(jsonString))
}
}
```

Two setup functions which run sql files to first create tables and then insert data into them:

```go
func (d *DBManager) runSqlSetupFiles() {
// Check if the specified SQL file exists
sqlFilePath := filepath.Join(".", "sql", d.rebuildSql)
if _, err := os.Stat(sqlFilePath); os.IsNotExist(err) {
// If the file does not exist, log an error message
d.LogError(fmt.Sprintf("SQL file '%s' not found", sqlFilePath))
return
}

// Read the contents of the SQL file
sqlBytes, err := ioutil.ReadFile(sqlFilePath)
if err != nil {
// If there was an error reading the file, log the error message
d.LogError(err.Error())
return
}
sql := string(sqlBytes)

// Execute the SQL statements contained in the file
if err := d.db.Exec(sql).Error; err != nil {
// If there was an error executing the SQL, log the error message
d.LogError(err.Error())
return
}

// Log a message indicating that the SQL was executed successfully
d.Log("Executed " + d.rebuildSql)
}

func (d *DBManager) fillDB() {
// Define a function to be executed when the main function returns (i.e. in case of panic)
defer func () {
if r := recover(); r != nil {
// If a panic occurred, log a message indicating that the database fill failed
d.Log(fmt.Sprintf("Failed to fill database: %s", r))
}
}()

// Check if the specified SQL file exists
sqlFilePath := filepath.Join(".", "sql", d.insertSql)
if _, err := os.Stat(sqlFilePath); os.IsNotExist(err) {
// If the file does not exist, panic with an error message
panic(fmt.Sprintf("SQL file '%s' not found", sqlFilePath))
}

// Read the contents of the SQL file
sqlBytes, err := ioutil.ReadFile(sqlFilePath)
if err != nil {
// If there was an error reading the file, panic with the error
panic(err)
}
sql := string(sqlBytes)

// Execute the SQL statements contained in the file
if err := d.db.Exec(sql).Error; err != nil {
// If there was an error executing the SQL, panic with the error
panic(err)
}

// Log a message indicating that the SQL was executed successfully
d.Log("Executed " + d.insertSql)
}
```

This function logs all the tables which we created to the console:

```go
func (d *DBManager) logAllTables() {
// Execute a raw SQL query to retrieve the names of all tables in the "ws" schema
rows, err := d.db.Raw("SELECT table_name FROM information_schema.tables WHERE table_schema = 'public'").Rows()
if err != nil {
// If there was an error executing the query, log the error message
d.Log(err.Error())
}

// Initialize a string to store the log message
var log = "Tables: "

// Loop through the query results
for rows.Next() {
var table_name string
rows.Scan(&table_name)
// Append the table name to the log message
log += table_name + ", "
}

// Log the log message
d.Log(log)
}
```

To log what is happening inside the database manager, I used a logging system which supports different log levels, color highlighting and timestamps. The logging system is very simple to set up and only has two functions:

```go
func (d *DBManager) Log(s string) {
	// Log a message with the prefix "DatabaseManager: "
	log.Default().Println("DatabaseManager: ", s)
}

func (d *DBManager) LogError(message string) {
	// Create a red color function for log messages
	red := color.New(color.FgRed).SprintFunc()

	// Log an error message with the prefix "DatabaseManager: " and in red color
	log.Fatal("DatabaseManager: ", red(message))
}
```

The output looks like this:

```bash
2023/04/09 12:33:29 DatabaseManager:  Connected to database
2023/04/09 12:33:29 DatabaseManager:  &{db:0x14000362540 name:Postgres insertSql:insert.sql rebuildSql:rebuild.sql}
2023/04/09 12:33:29 DatabaseManager:  Executed rebuild.sql
2023/04/09 12:33:29 DatabaseManager:  Tables: energy_data, weather_data, 
2023/04/09 12:33:29 DatabaseManager:  Executed insert.sql
2023/04/09 12:33:29 DatabaseManager:  Tables: energy_data, weather_data, 
```

Logs like these are very useful to debug the application. Especially the timestamps and the origin of the log message can be very helpful.

But to get to the most important part of the database manager, we have to look at the CRUD functions. These functions
are used to create, read, update and delete data from the database and are essential for the Rest API.

To manipulate all data from the database I used a GORM model which is a struct that represents a table in the database.
The ORM is defined in like this:

```go 
// WeatherData ORM 
type WeatherData struct {
    Timestamp        time.Time `gorm:"column:timestamp"`
    Temperature      float64   `gorm:"column:temperature"`
    Humidity         float64   `gorm:"column:humidity"`
    Pressure         float64   `gorm:"column:pressure"`
    ObstacleDetected bool      `gorm:"column:obstacle_detected"`
    LightIntensity   float64   `gorm:"column:light_intensity"`
}
```

Next we have different functions which are used to manipulate data:

This function is used to gather all weather data from one specific timestamps and returns like all of my CRUD functions
a JSON string:

```go
func (d *DBManager) GetWeatherDataByTimestampJSON(timestamp string) (string, error) {
    // Validate the format of the input timestamp using a regular expression
    validTimestamp := regexp.MustCompile(`^\d{4}-\d{2}-\d{2}T\d{2}:\d{2}:\d{2}Z$`)
    if !validTimestamp.MatchString(timestamp) {
    // Return an error if the format is invalid
    return "", fmt.Errorf("Invalid timestamp format: %s", timestamp)
    }
    
    // Parse the timestamp string into a time.Time value
    timestampParsed, err := time.Parse(time.RFC3339, timestamp)
    if err != nil {
    // Return the error if there was a problem parsing the timestamp
    return "", err
    }
    
    // Retrieve the weather data with the specified timestamp
    var weatherData WeatherData
    result := d.db.Table("weather_data").Where("timestamp = ?", timestampParsed).First(&weatherData)
    if result.Error != nil {
    // Return the error if there was a problem retrieving the data
    return "", result.Error
    }
    
    // Check if no rows were affected (i.e. no data was found)
    if result.RowsAffected == 0 {
    // Return a message indicating that no data was found
    return "No weather data found for the specified timestamp", nil
    }
    
    // Marshal the weather data into a JSON string
    weatherDataJSON, err := json.Marshal(weatherData)
    if err != nil {
    // Return the error if there was a problem marshaling the data
    return "", err
    }
    
    // Return the JSON string
    return string(weatherDataJSON), nil
}
```

In contrast, this function returns all weather data from the database, not just one specific timestamp:

```go
func (d *DBManager) GetAllWeatherDataJSON() ([]byte, error) {
    // Retrieve all weather data records
    var data []WeatherData
    result := d.db.Table("weather_data").Find(&data)
    if result.Error != nil {
    // Return the error if there was a problem retrieving the data
    return nil, result.Error
    }
    if result.RowsAffected == 0 {
    // Return an error if no data was found
    return nil, errors.New("no weather data found")
    }
    
    // Marshal the weather data into a JSON string
    jsonData, err := json.Marshal(data)
    if err != nil {
    // Return the error if there was a problem marshaling the data
    return nil, err
    }
    
    // Return the JSON string
    return jsonData, nil
    }
    ```
    
    Of course, we also want to be able to delete data. This function uses a timestamp to delete a specific weather data
    record:
    
    ```go
    func (d *DBManager) DeleteWeatherDataJSON(jsonStr string) (string, error) {
    // Unmarshal the JSON string into a struct
    var data struct {
    Timestamp string `json:"timestamp"`
    }
    err := json.Unmarshal([]byte(jsonStr), &data)
    if err != nil {
    // Return the error if there was a problem unmarshaling the JSON
    return "", err
    }
    
    // Parse the "timestamp" field into a time.Time value
    timestamp, err := time.Parse(time.RFC3339, data.Timestamp)
    if err != nil {
    // Return the error if there was a problem parsing the timestamp
    return "", err
    }
    
    // Delete the weather data with the specified timestamp
    result := d.db.Table("weather_data").Where("timestamp = ?", timestamp).Delete(&WeatherData{})
    if result.Error != nil {
    // Return the error if there was a problem deleting the data
    return "", result.Error
    }
    
    // Check if no rows were affected (i.e. no data was found)
    if result.RowsAffected == 0 {
    // Return a message indicating that no data was found
    return "No weather data found for the specified timestamp", nil
    }
    
    // Return a success message
    return "Weather data deleted", nil
}
```

To update data we also need a timestamp to identify the entry we want to update with this function:

```go
func (d *DBManager) UpdateWeatherDataJSON(jsonStr string) (string, error) {
    // Unmarshal the JSON string into a `WeatherData` struct
    var data WeatherData
    err := json.Unmarshal([]byte(jsonStr), &data)
    if err != nil {
    // Return the error if there was a problem unmarshaling the JSON
    return "", err
    }
    
    // Retrieve the existing weather data with the same timestamp
    existingData := WeatherData{}
    result := d.db.Table("weather_data").Where("timestamp = ?", data.Timestamp).First(&existingData)
    if result.Error != nil {
    // Return the error if there was a problem retrieving the existing data
    return "", result.Error
    }
    if result.RowsAffected == 0 {
    // Return a message indicating that no data was found
    return "No weather data found for the specified timestamp", nil
    }
    
    // Update the existing weather data
    result = d.db.Table("weather_data").
    Where("timestamp = ?", data.Timestamp).
    Updates(WeatherData{
    Temperature:      data.Temperature,
    Humidity:         data.Humidity,
    Pressure:         data.Pressure,
    ObstacleDetected: data.ObstacleDetected,
    LightIntensity:   data.LightIntensity,
    })
    if result.Error != nil {
    // Return the error if there was a problem updating the data
    return "", result.Error
    }
    
    // Return a success message
    return "Weather data updated", nil
}

```

Lastly, we want to create new weather records. This function takes in a JSON string and creates the record in the
database:

```go
func (d *DBManager) CreateWeatherDataJSON(jsonStr string) (string, error) {
    // Unmarshal the JSON string into a `WeatherData` struct
    var data WeatherData
    err := json.Unmarshal([]byte(jsonStr), &data)
    if err != nil {
    // Return the error if there was a problem unmarshaling the JSON
    return "", err
    }
    
    // Check if data with the same timestamp already exists
    existingData := WeatherData{}
    result := d.db.Table("weather_data").Where("timestamp = ?", data.Timestamp).First(&existingData)
    if result.RowsAffected > 0 {
    // Return a message indicating that the data already exists
    return "Weather data already exists for the specified timestamp", nil
    }
    
    // Create the weather data
    result = d.db.Table("weather_data").Create(&data)
    if result.Error != nil {
    // Return the error if there was a problem creating the data
    return "", result.Error
    }
    
    // Return a success message
    return "Weather data created", nil
}
```

## API

All these operations are getting called by the FiberApp, the second essential component of the application. The FiberApp
is the other object that is instantiated in the main function.
It is responsible for handling HTTP endpoints, middleware, metrics and authentication. After the DBManager is created
the FiberApp follows.

This is the constructor of the FiberApp:

```go
// NewFiberApp constructor for fiber
func NewFiberApp() *FiberApp {
    return &FiberApp{
        fiberApp: fiber.New(),
        metrics:  NewMetrics(),
    }
}
```

The FiberApp consists of a Fiber instance and a metric instance that is used to collect metrics about the application.

The FiberApp has some useful auxiliary functions like the DBManager, but I will not go into these again, only the new
functionality.

The main function of the FiberApp is the setupRoutes function. As the name suggests, it sets up all the routes of the
application.

I will go step by step through this function to explain what is happening.

First we set up middleware which is used for logging incoming requests and logging outgoing responses.
It makes it very easy to debug the application and see what is happening. Then we serve the static files of the
frontend.

```go
// add middleware to log input and output for all routes
f.fiberApp.Use(f.logMiddleware)

// Serve static files from the "static" directory
f.fiberApp.Static("/", "./web")
```

### api/weather/:timestamp

After that, we set up all the routes of the application. The first route delivers data from a specific timestamp. All
these routes call the CRUD functions in the DBManager.

```go
f.fiberApp.Get("api/weather/:timestamp", func (c *fiber.Ctx) error {
// Get the timestamp from the URL parameters
timestamp := c.Params("timestamp")

// URL-decode the timestamp
decodedTimestamp, err := url.QueryUnescape(timestamp)
if err != nil {
// Return a bad request error if the timestamp format is invalid
return c.Status(fiber.StatusBadRequest).SendString("Invalid timestamp format")
}

// Call the `GetWeatherDataByTimestampJSON` method from the `dbManager` object
weatherData, err := dbManager.GetWeatherDataByTimestampJSON(decodedTimestamp)
if err != nil {
// Increment the error count in the metrics and return the error
f.metrics.IncrementErrorCount(c.Route().Path)
return c.SendString(err.Error())
}

// Increment the request count in the metrics
f.metrics.IncrementRequestCount(c.Route().Path)

// Return the weather data
return c.SendString(weatherData)
})
```

Returns:

```json
{
    "Timestamp": "2022-02-03T00:00:00Z",
    "Temperature": 23,
    "Humidity": 57.4,
    "Pressure": 1016.4,
    "ObstacleDetected": true,
    "LightIntensity": 1025.5
}
```

or

```
No weather data found for the specified timestamp
```

or

```
Some kind of error message
```

### api/weather

A GET request to receive all weather data entries.

```go
f.fiberApp.Get("api/weather", func (c *fiber.Ctx) error {
// Call the GetAllWeatherDataJSON method from the dbManager object
weatherData, err := dbManager.GetAllWeatherDataJSON()
if err != nil {
// If an error occurs, increment the error count for this route
f.metrics.IncrementErrorCount(c.Route().Path)
// Return the error message to the client
return c.SendString(err.Error())
}

// Increment the request count for this route
f.metrics.IncrementRequestCount(c.Route().Path)
// Return the weather data to the client
return c.Send(weatherData)
})
```

Returns:

```json
[
	{
		"Timestamp": "2022-02-03T00:00:00Z",
		"Temperature": 23,
		"Humidity": 57.4,
		"Pressure": 1016.4,
		"ObstacleDetected": true,
		"LightIntensity": 1025.5
	},
	{
		"Timestamp": "2022-02-04T00:00:00Z",
		"Temperature": 23.5,
		"Humidity": 54.6,
		"Pressure": 1016.7,
		"ObstacleDetected": true,
		"LightIntensity": 1025.8
	},
	{
		"Timestamp": "2022-03-02T00:00:00Z",
		"Temperature": 22.1,
		"Humidity": 63.8,
		"Pressure": 1016.2,
		"ObstacleDetected": false,
		"LightIntensity": 0
	},
	{
		"Timestamp": "2022-02-01T00:00:00Z",
		"Temperature": 31.5,
		"Humidity": 65.2,
		"Pressure": 1094.7,
		"ObstacleDetected": false,
		"LightIntensity": 1024.8
	}
]
```

or

```
Some kind of error message
```

### api/weather/delete

A Delete request to delete an specific entry.

```go
f.fiberApp.Delete("api/weather/delete", func (c *fiber.Ctx) error {
// Get the JSON data from the request body
jsonStr := string(c.Body())

// Call the DeleteWeatherDataJSON method from the dbManager object
result, err := dbManager.DeleteWeatherDataJSON(jsonStr)
if err != nil {
// Increment error count in the metrics object and log the error
f.metrics.IncrementErrorCount(c.Route().Path)
fmt.Println("Failed to delete weather data:", err)
// Return a 500 Internal Server Error status code
return c.SendStatus(fiber.StatusInternalServerError)
}

// If no weather data was found for the specified timestamp
if result == "No weather data found for the specified timestamp" {
// Increment error count in the metrics object and return a 404 Not Found status code
f.metrics.IncrementErrorCount(c.Route().Path)
return c.SendStatus(fiber.StatusNotFound)
}

// Increment request count in the metrics object
f.metrics.IncrementRequestCount(c.Route().Path)
// Return a success message
return c.SendString("Weather data deleted successfully.")
})
```

Returns:

```
Weather data updated
```

or

```
Not Found
```

or

```
Some kind of error message
```

### api/weather/update

And PUT request to update weather data.

```go
f.fiberApp.Put("api/weather/update", func (c *fiber.Ctx) error {
// Get JSON data from the request body
jsonStr := string(c.Body())

// Call the UpdateWeatherDataJSON method from the dbManager object
result, err := dbManager.UpdateWeatherDataJSON(jsonStr)
if err != nil {
// If there is an error, increment the error count and return the error message
f.metrics.IncrementErrorCount(c.Route().Path)
return c.SendString(err.Error())
}

// If the update was successful, increment the request count
f.metrics.IncrementRequestCount(c.Route().Path)
return c.SendString(result)
})
```

Response:

```
Weather data updated
```

or

```
No weather data found for the specified timestamp
```

or

```
Some kind of error message
```

### api/weather/create

```go
// Handle HTTP POST request to the "/api/weather/create" endpoint
f.fiberApp.Post("api/weather/create", func (c *fiber.Ctx) error {
// Get the JSON data from the request body
jsonStr := string(c.Body())

// Call the `CreateWeatherDataJSON` method from the `dbManager` object
result, err := dbManager.CreateWeatherDataJSON(jsonStr)
if err != nil {
// Increment the error count for the current route
f.metrics.IncrementErrorCount(c.Route().Path)

// Return the error message
return c.SendString(err.Error())
}

// Increment the request count for the current route
f.metrics.IncrementRequestCount(c.Route().Path)

// Return the result of the `CreateWeatherDataJSON` method
return c.SendString(result)
})
```

Response:

```
Weather data already exists for the specified timestamp
```

or

```
Weather data created successfully
```

or

```
Some kind of error message
```

### api/metrics

A GET request to the `/api/metrics` endpoint returns the metrics in JSON format.

```go
f.fiberApp.Get("api/metrics", func (c *fiber.Ctx) error {
// Retrieve metrics from the metrics object
metrics := f.metrics.GetMetrics()

// Increment the request count for the api/metrics endpoint
f.metrics.IncrementRequestCount(c.Route().Path)

// Return the metrics in JSON format
return c.JSON(metrics)
})
```

Response:

```json
{
  "errorCount": {
    "/api/weather/:timestamp": 1
  },
  "requestCount": {
    "/api/metrics": 8,
    "/api/weather": 1,
    "/api/weather/create": 1,
    "/api/weather/delete": 1,
    "/api/weather/update": 1
  }
}
```

### /

Route which returns the index.html file.

```go
f.fiberApp.Get("/", func (c *fiber.Ctx) error {
f.metrics.IncrementRequestCount(c.Route().Path)
//returns main html page
return c.SendFile("./web/index.html")
})
```

Returns the main page of the web application:

Main page

The Frontend of my page also got some aesthetic improvements, but because my research only focus on the backend I will
not cover that.
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

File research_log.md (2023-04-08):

# Research Log

In this document the current state of the research phase of the project. This log might be very messy and unstructured, as it only servers as a personal log for me to keep track of my progress.

## Starting out with the project

I'm currently planning to get a good general overview of Golang. I want to know how to use the language, which libraries and what architectures to use.

I found plenty of info material I want to read and watch through:

-https://www.youtube.com/watch?v=YS4e4q9oBaU
-https://madappgang.com/blog/backend-development-with-golang/
-https://www.youtube.com/watch?v=bj77B59nkTQ

In addition to that I plan to build the new backend in a separate git repository. This way I can easily switch between the old and the new backend. 
The git repository will be added as submodule to the main project, so it can be easily integrated into the project.

## Update on the submodule approach

After doing some research on this topic during the weekend, it turns out that all commits of the included submodule will not show up in the commits of the main project. That would be okay,
if the commits to our projects weren't important for our grade. So I decided to just import the subrepo as a normal folder and push it in the end to the other repository.

## Choosing a backend framework

During the last weekend, I also did some research on what backend frameworks to use with Golang. I found out that there are a lot of interesting solutions out there:

#### Web-Frameworks

To build a API with Golang, you can use the following frameworks:

Gin - A lightweight and fast HTTP web framework with a focus on high performance.
Echo - A high-performance, minimalist Go web framework with a focus on RESTful APIs.
Fiber - A fast and easy-to-use web framework with a focus on performance and minimalism.
Chi - A lightweight, flexible and fast HTTP router and micro-framework for Go.
Revel - A full-stack web framework for building scalable and maintainable web applications in Go.
Gorilla - A toolkit of packages for building web applications and services in Go.
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

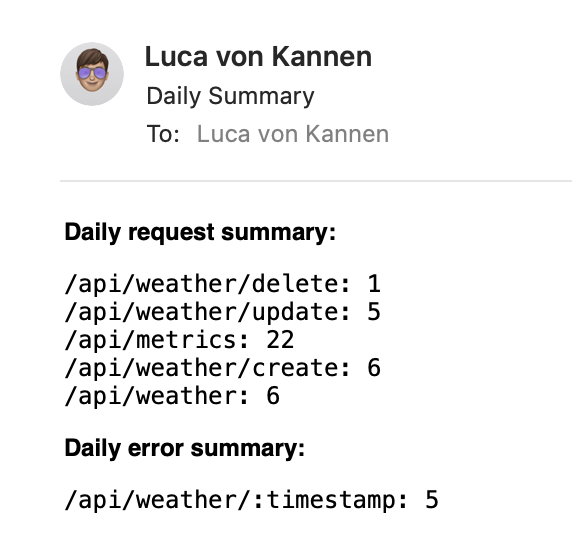
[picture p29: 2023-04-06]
images/daily.png

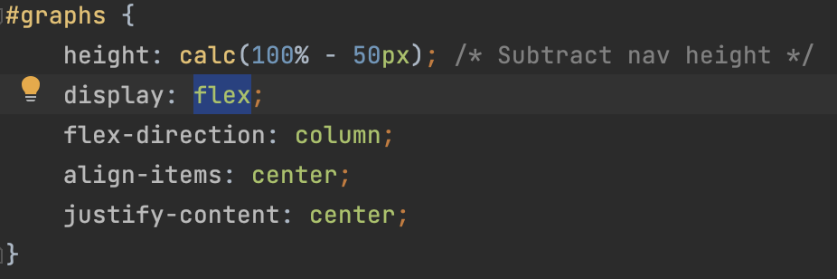
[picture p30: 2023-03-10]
images/css.png

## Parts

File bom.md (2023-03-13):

# Wiring Diagram

(Reviewed by Luca(not me))

This wiring diagram gives a visual representation of an electrical circuit or system that shows the physical connections between its components and wires. It uses symbols and shapes to depict the different electrical components and their interconnections. By using wiring diagrams, electricians and engineers can understand and troubleshoot complex electrical systems easily.

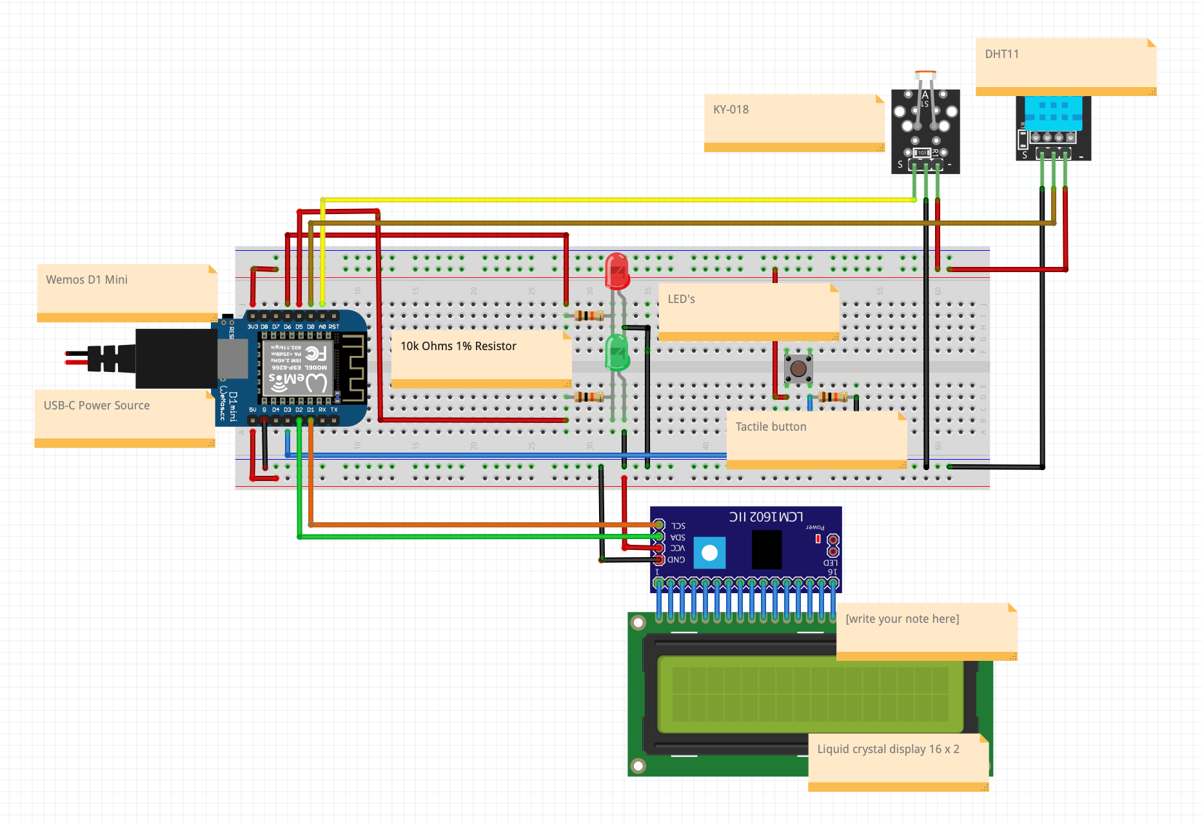
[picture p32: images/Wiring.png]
Wiring


# Bill of Materials

This Bill of Materials (BOM) is a comprehensive list of all the materials, components, and instructions needed to produce Weather Wizard. BOM's are commonly used in manufacturing, product development, and engineering to plan purchases, estimate costs, control inventory, and minimize production delays and waste.

| Part Number | Part Name | Part Description | Part Quantity | Manufacturer | Part Cost | Subtotal | URL |
|---|---|---|---|---|---|---|---|
| / | LED set | 0.5W 8Mm 5 Kleur Ultra-Heldere Led Wit Geel Blauw Groen Rood Licht Lamp Emitting diodes Hoge Helderheid | 1 | HESAI | € 0,01 | € 0,01 | https://de.aliexpress.com/item/32822066523.html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 | 
| 10k resistor | Resistors | Set of 20 10K Ohm resistors | 1 | GOHJMY | € 0,12 | € 0,12 | https://de.aliexpress.com/item/1005003276086924.html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 |
| 1602a | LCD Display 16*2 | Shows characters with white text and blue backlight | 1 | QAPASS | € 4 | € 4 | https://www.tinytronics.nl/shop/en/displays/lcd/lcd-display-16*2-characters-with-white-text-and-blue-backlight |
| KY-015 | KY-015 DHT11 | Temperature and Humidity Sensor | 1 | KEYES | € 2,60 | € 2,60 | https://www.prolectra.nl/home/301-ky-015-dht11-temperature-and-humidity-sensor-module.html |
| 001204 | TACT12X12X7.3MM | Tactile Pushbutton Switch Momentary 4pin | 1 | / | € 0,25 | € 0,25 | https://www.tinytronics.nl/shop/en/switches/manual-switches/pcb-switches/tactile-pushbutton-switch-momentary-4pin-12*12*7.3mm |
| ESP8266 | Wemos D1 Mini V4 | TYPE-C USB Wifi Internet Of Things Board Based ESP8266 | 1 | BOLANTEDZ | € 2,35 | € 2,35 | https://nl.aliexpress.com/item/1005004527213280.html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 |
| 000071 | BB830P | Breadboard with 830 pins | 1 | / | € 4 | € 4 | https://www.tinytronics.nl/shop/en/tools-and-mounting/prototyping-supplies/breadboards/breadboard-830-points |
| i2c | I2C Twi Spi Serial Interface Board | 1602A Backpack | 1 | TZT | € 1,22 | € 1,22 | https://nl.aliexpress.com/item/32649843103.html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 |
| 000544 | DUPOMM10 | DuPont Jumper wire Male-Male 10cm 10 wires | 2  / 20 in total | DUPONT | € 0,50 | € 1 | https://www.tinytronics.nl/shop/en/cables-and-connectors/cables-and-adapters/prototyping-wires/dupont-compatible-and-jumper/dupont-jumper-wire-male-male-10cm-10-wire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 |

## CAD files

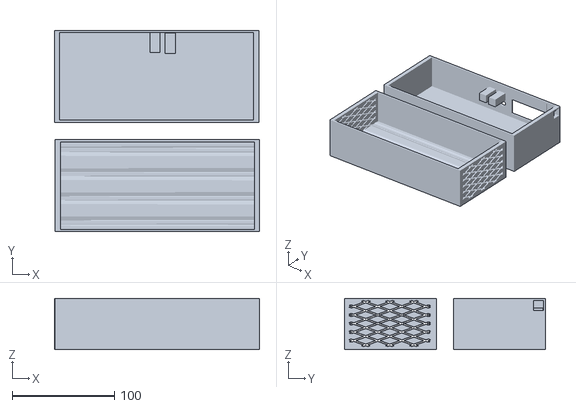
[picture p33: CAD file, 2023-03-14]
physical-design/prototype 0.15.stl
200.7 x 197.0 x 50.0

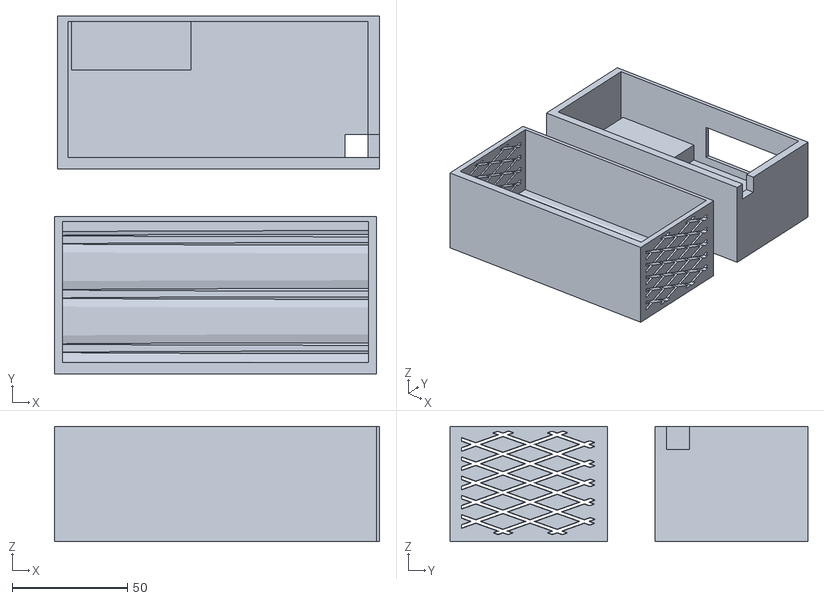
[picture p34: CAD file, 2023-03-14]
docs/physical-design/prototype 0.2 rotated.stl
141.3 x 155.5 x 50.0

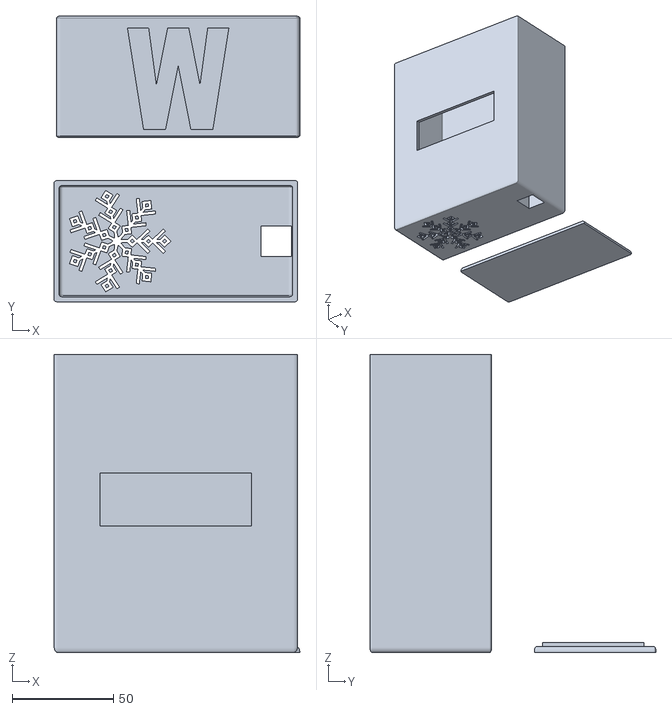
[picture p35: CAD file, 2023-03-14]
docs/physical-design/Weather Wizard Final.stl
121.1 x 141.0 x 147.0

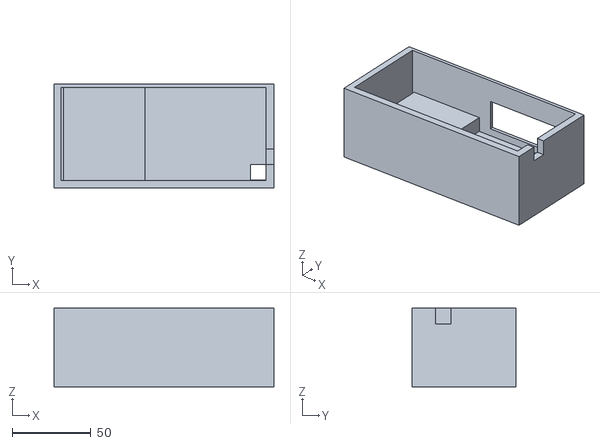
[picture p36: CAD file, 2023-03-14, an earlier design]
physical-design/prototype 0.1.stl
140.0 x 66.5 x 50.0

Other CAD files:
docs/physical-design/prototype 0.2.stl
physical-design/prototype 0.2.stl

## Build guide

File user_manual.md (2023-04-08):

# User Manual

(Reviewed by Rafail)
- Tips adding exact commands to run
- Add exact paths to files
- Add exact names of files
- Maybe add links to download (Will add to second review)

## INTRODUCTION
The Weather Wizard is an IOT device that collects weather data, including temperature, humidity, and light intensity (and soon more), and sends it to the backend where data gets saved in a database. From the backend, the data will be fetched
by the frontend and displayed in graphs. The Weather Wizard is designed for weather enthusiasts, students, and researchers who want to collect accurate weather data.

The Weather Wizard's features include:

- Collects temperature, humidity, and light intensity data
- Sends data to a web application for analysis
- Easy to use and set up
- Compact casing

## INSTALLATION INSTRUCTIONS: ARDUINO IDE AND LIBRARIES

To start building your own Weather Wizard, you will need to install the Arduino IDE and all the necessary libraries. Here are the steps to install:

1. Download and install the latest version of the Arduino IDE from the official Arduino website.
2. Open the Arduino IDE and navigate to Sketch > Include Library > Manage Libraries.
3. Search for and install the following libraries:

- LiquidCrystal_I2C
- ESP8266WiFi
- ESP8266HTTPClient
- WiFiClient
- WiFiManager
- Adafruit_DHT

Some of these libraries might be already installed on your computer, others might not.
If you are unsure, you can always check the list of installed libraries by navigating
to Sketch > Include Library > Manage Libraries. If some libraries are not shown
in the findable in the Library manager, then you have to install the .zip file of the library manually.
Usually you find the .zip file under the "Releases" tab of the library's GitHub repository. After downloading them,
from the releases, you can include them like this:

1. Navigate to Sketch > Include Library > Add .ZIP Library.
2. Select the .zip file of the library you want to install.
3. Repeat this step for all the libraries you want to install.

## BUILD INSTRUCTIONS EMBEDDED DEVICE

Here are the steps to build your IoT Weather Station:

1. Gather the necessary components, which are listed under Embedded → BOM and wiring diagram -> BOM
2. Solder the components together according to the wiring diagram, which is also under Embedded → BOM and wiring diagram -> Wiring diagram
3. Place the components in the casing
4. Place the ceiling of the casing on top and glue it in place (preferably with hot glue)

## INSTALLATION INSTRUCTIONS EMBEDDED CODE

To install the code on your embedded device, follow these steps:

1. Clone the repository from GitLab to your computer. You can do that like this:
2. Open a terminal and navigate to the folder where you want to clone the repository.
3. Run the following command:

```
git clone https://gitlab.fdmci.hva.nl/IoT/2022-2023-feb-jun/individual-project/iot-kannenl1.git
```

4. In the IDE navigate to file and then Open. Select the main.ino file in the ./emb directory.
5. Connect your Wemos D1 Mini to your computer and select the USB-C port in the Tools > Port menu.
5. Upload the code by clicking the Upload button.

## NETWORK CONFIGURATION OF EMBEDDED DEVICE

To configure the Wi-Fi network on your Weather Wizard, follow these steps:

1. Power on the Weather Wizard and wait for it to start up.
2. Wait a few seconds until the Wemos starts in AP mode. A Wi-Fi network named "WeatherWizard AutoConnect" will appear.
3. Connect to this Wi-Fi network with your computer or mobile device.
4. A window will open which will ask you to connect to a Wi-Fi network. Go to Scan Network, select your network and enter the password.

## To install Docker Desktop, follow these steps:

1. Download and install Docker Desktop from the official Docker website.
2. Open Docker Desktop and wait for it to start up. It won't work if the Docker Daemon is not running.
3. Open a terminal and run the following command to check if Docker is installed correctly:

```
docker --version
```
It should display the version of Docker that you have installed.

4. Navigate to the folder docker-container which is located in the root directory of the repository.
5. Run the following command to build the Docker image:

```
docker-compose up
```

## USAGE OF EMBEDDED DEVICE

1. Connect the device to a power source.
2. Wait for the Wemos to start up.
3. Wait for the Wemos to connect to the Wi-Fi network or set up a new Wi-Fi network.
4. Start the backend and frontend in their respective Docker containers.
5. Open "localhost" in your browser to access the frontend of the Weather Wizard.

## How the frontend works

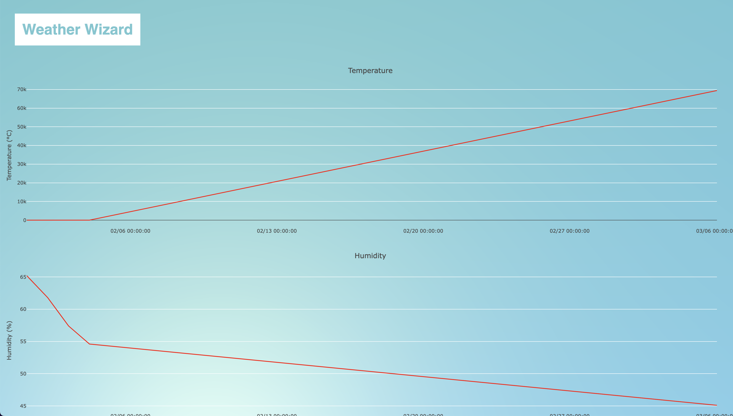
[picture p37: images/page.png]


The frontend is a web application that displays the weather data in graphs. By using Ajax, it communicates in the background with the
backend to retrieve the weather data. It updates every 10 seconds. By clicking the Logo you can also refresh instantly. You hover over the graphs to get more detailed information about the time and
values of the data points. The graphs are also interactive, you can zoom in and out, take screenshots, and download them as a .png file.
A menu for these functions appears as soon as you hover over one of the graphs.

## API DOCUMENTATION

This API provides CRUD (Create, Read, Update, Delete) operations for managing weather data.

## Methods:

- POST /?action=weather_data - Creates a new weather data point
- PUT /?action=weather_data - Updates an existing weather data point
- DELETE /?action=weather_data - Deletes an existing weather data point
- GET /?action=weather_data - Retrieves all the weather data points

## Parameters:

- timestamp: The timestamp of the weather data point (required)
- new_timestamp: The new timestamp for an updated weather data point
- temperature: The temperature of the weather data point (required)
- humidity: The humidity of the weather data point (required)
- pressure: The pressure of the weather data point (required)
- obstacle_detected: Whether an obstacle was detected (required)
- light_intensity: The light intensity of the weather data point (required)

### __Every request returns a JSON file__
- Success: JSON object with a message
- Failure: JSON object with an error message

# Details

### POST request

To create a new weather data point:

```json
{
    "timestamp": "2022-03-07 12:00:00",
    "temperature": 25,
    "humidity": 70,
    "pressure": 1013,
    "obstacle_detected": false,
    "light_intensity": 100
}
```

Response:
```json
{
    "message": "Weather data added successfully."
}
```

### GET request

To retrieve all the weather data points:

Response:

```json
[
  {
    "timestamp": "2022-12-09",
    "temperature": "69420.3",
    "humidity": "45.1",
    "pressure": "1013.2",
    "obstacle_detected": "1",
    "light_intensity": "800.2"
  },
  {
    "timestamp": "2022-12-10",
    "temperature": "69420.3",
    "humidity": "45.1",
    "pressure": "1013.2",
    "obstacle_detected": "1",
    "light_intensity": "800.2"
  }
]
```

### PUT request
To update an existing weather data point:

Request:

```json
{
"timestamp": "2022-03-07 12:00:00",
"new_timestamp": "2022-03-07 13:00:00",
"temperature": 25,
"humidity": 70,
"pressure": 1013,
"obstacle_detected": false,
"light_intensity": 100
}
```

Response:

```json
{
"message": "Weather data updated successfully."
}
```

### DELETE request

To delete an existing weather data point:

Request:

```json
{
"timestamp": "2022-03-07 12:00:00"
}
```

Response:

```json
{
"message": "Weather data deleted successfully."
}
```

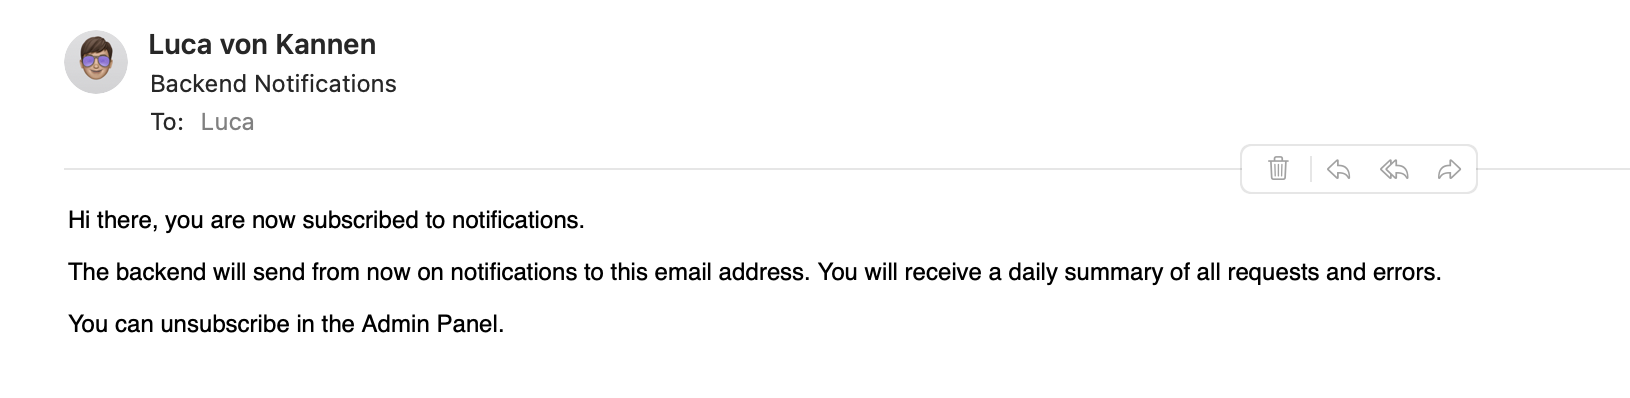
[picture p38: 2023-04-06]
images/setupmail.png

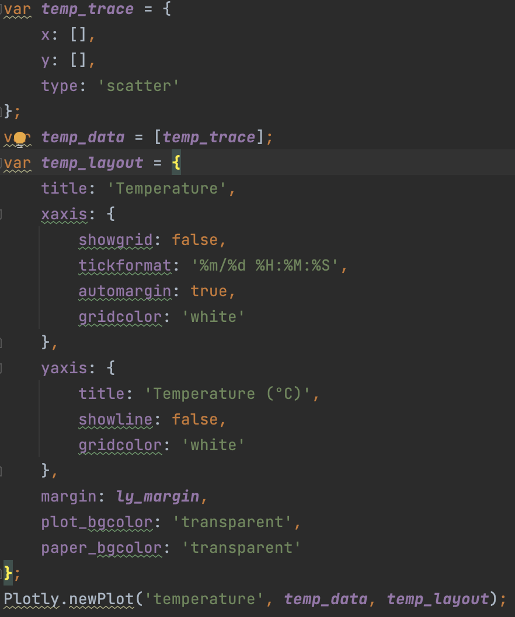
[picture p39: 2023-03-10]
images/building_graph.png

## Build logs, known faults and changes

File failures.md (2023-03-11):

(Reviewed by Rafail)

# Failures in Physical Design
Of course, there are failures in the process of developing a physical design. This document is a collection of failures and solutions to the mistakes that I have made.

## Failure 1: Trying to learn too many things at once
Since I still had my German exams here in Amsterdam, I was not able to work on the project as much as I wanted to. I initially started designing with Tinkercad, but later switched to the more professional software FreeCAD. This was not a good decision because the learning curve of FreeCAD is very steep, and I was not able to invest that much time in learning the software. As a result, I was forced to switch back to Tinkercad. Tinkercad might not be the best software for 3D designing, but it is very easy to learn.

## Failure 2: First prototype

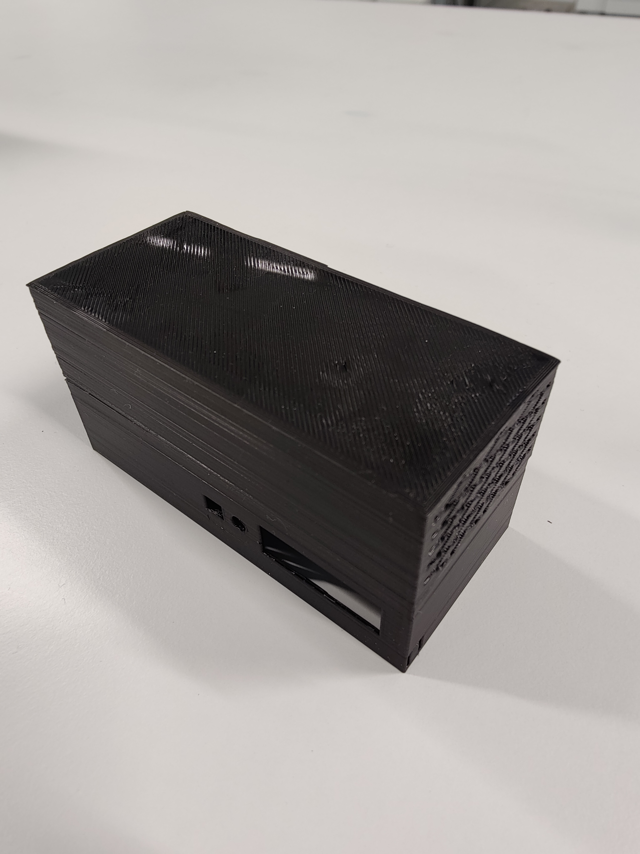
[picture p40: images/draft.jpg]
First prototype


This was the draft before I made the real first prototype. It had many design flaws. Since the size of it was too big, it didn't fit in the 3D printer. I had to scale it down to make it smaller, but this made the design unusable because the measurements for the components were wrong. Another problem was the fact that I wanted to create a case with holes for the sensors already in it. This was a bad idea because I was not entirely sure about which sensors I wanted to use. I printed the case anyway to get a feeling for the result.

In the next iteration, I fixed many of the mentioned problems and created a new design. This time, I changed the sizing and removed the holes for the sensors, so it would fit in the printer.

Second prototype

It also had a few flaws and would be changed later, but it was a good start.

## Failure 3:
The case from the last picture looks good, but I could not print my model because my printer stopped working in the middle of the print. I lost a day of printing and had to reprint it one day later. The staff of the Makerslab thinks that the printer lost power.

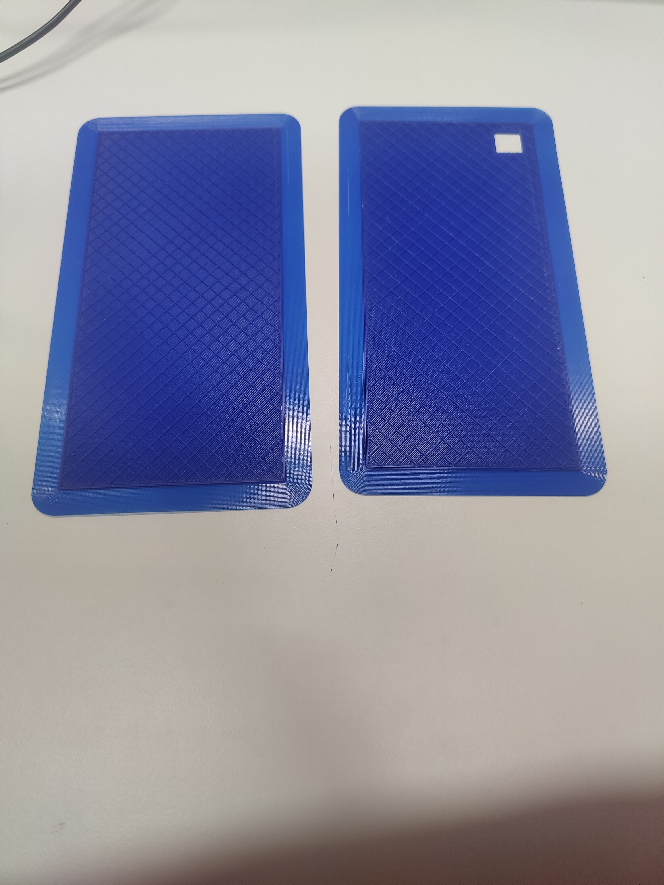
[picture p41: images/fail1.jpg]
fail1


The only thing I could do was to print the case again.

## Failure 4:
The blue model from the last picture also had problems with the filament structure at the bottom. They are not visible in this picture, but this picture should give you an idea of the problem:

fail2

A possible problem is that the plate of the printer was not properly cleaned before printing. This could be the reason why the filament did not stick to the plate. Printing the exact same model again but with a different printer helped.

This was the result:

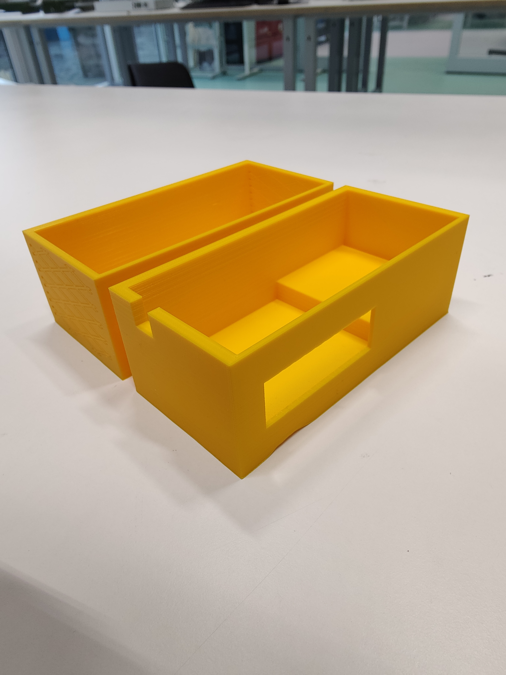
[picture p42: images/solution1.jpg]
Solution

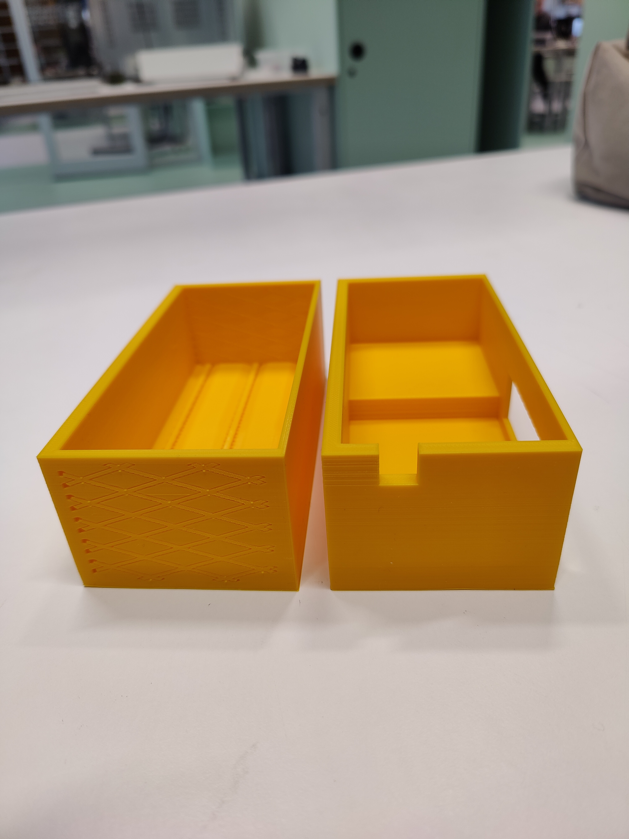
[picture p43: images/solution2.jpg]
Solution


## Failure 5:
After fighting with a lot of problems during the printing process, the last yellow model was of course usable, but not perfect. It had an extra layer where I could place the sensors and drill holes for the sensors. It had ventilation holes and cutouts for the cables. The problem was that the ventilation holes were too small, and air couldn't get through. If I made the holes bigger, the case would probably not be waterproof anymore. I had to find a solution for this problem.

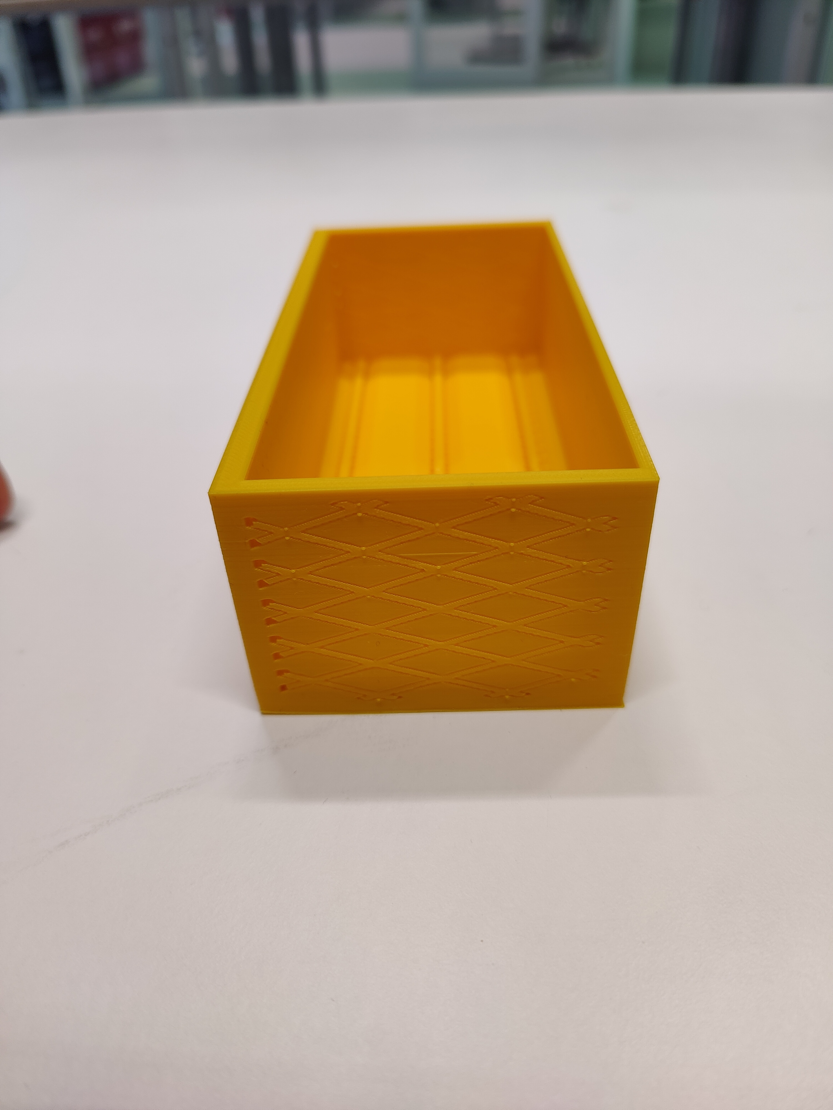
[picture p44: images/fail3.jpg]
fail3


My solution was the latest model. It has ventilation holes at the bottom and doesn't have two parts anymore, which should make assembly and printing easier. It also has a cutout for the cables and rounded corners to make it look better.

The model is currently printing:

Solution

These are images of the Weather Wizard in the final design

Solution
Solution

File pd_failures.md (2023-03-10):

# Failures

### First draft and experimenting with 3D-printing

This is the first draft of the enclosure. It is made of 15 mm thick ABS plastic and is printed on an Ultimaker 3D printer. It was designed with TinkerCAD. However, the shape of the housing is fully unsuitable, therefore probably a rectangular structure is better.
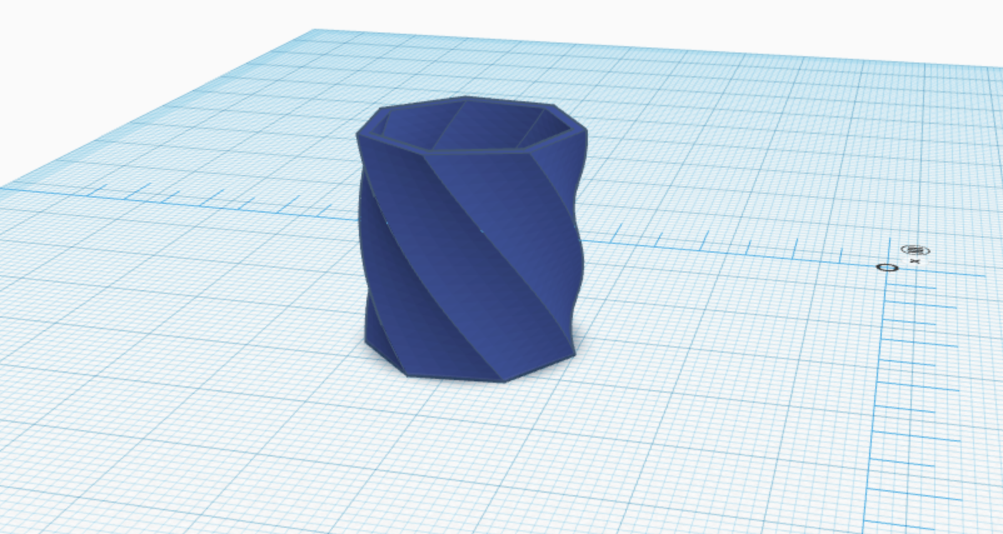
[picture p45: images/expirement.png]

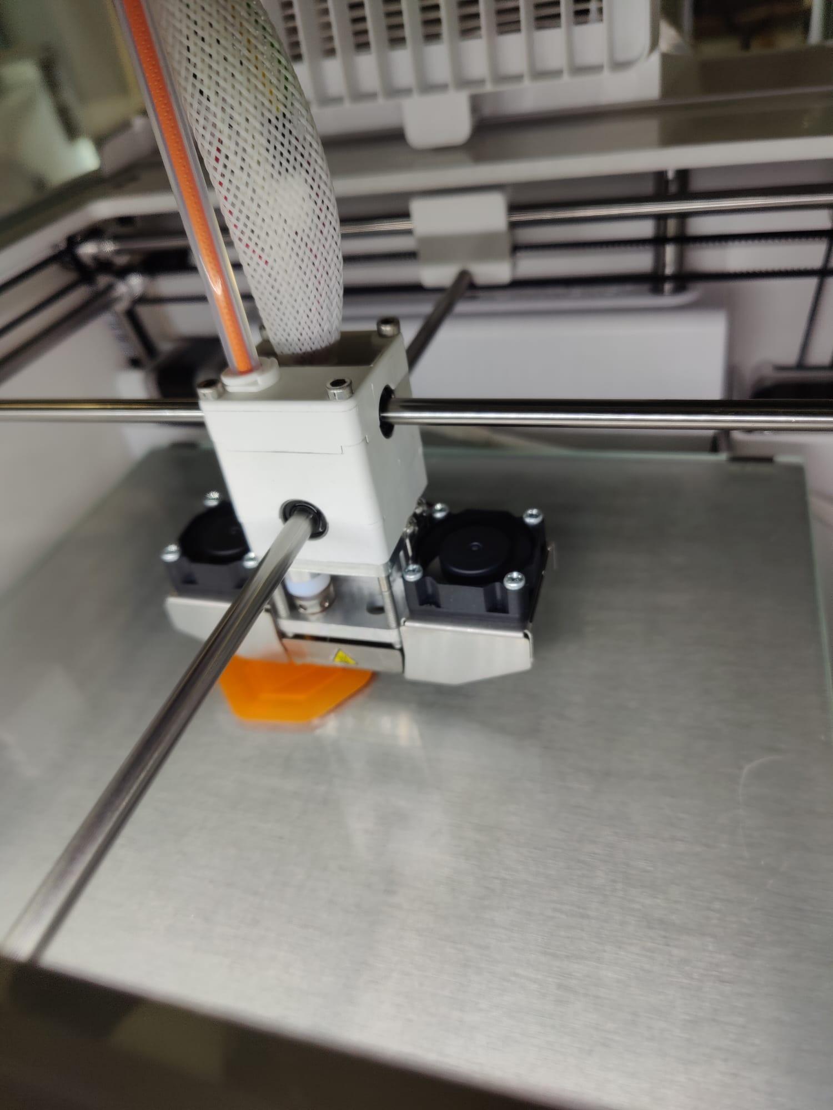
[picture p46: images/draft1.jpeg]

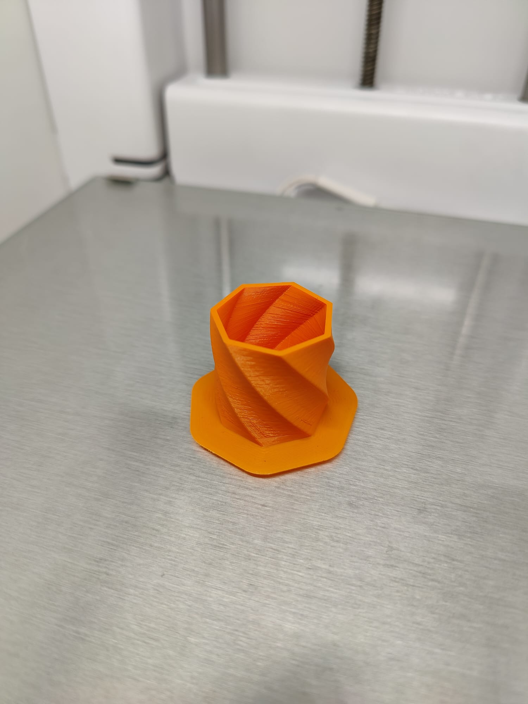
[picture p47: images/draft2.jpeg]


- ### First draft and expermenting with 3D-printing

- ### First draft and expermenting with 3D-printing

- ### First draft and expermenting with 3D-printing

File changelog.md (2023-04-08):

# Changelog

On this page you can find the changelog of the research of the WeatherWizard project.
The changes are only described very briefly. For more information, please refer the to the documentation of the implementation.

# Backend overview

- Build Rest API with all CRUD operations
- Created a new Postgres database in Docker
- Build a Metric system to track the usage of the API
- Improved the dashboard of the web application
- Created Admin Panel to display the metrics and manage 
- Build authentication system for the Admin Panel
- Build a notification system which sends emails with updates from the backend
- Created modern Logging system with log levels, colors and timestamps
- Build development environment with automated scripts and air reload
- Created Grafana dashboard as comparison to the web application dashboard
- Wrote exemplary unit tests for the backend

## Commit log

2023-02-06 Added sample readme with all markdown features
2023-02-17 Added images and description for the first draft of a case
2023-02-18 File structure for emb, fixed issues in db, added first script for arduino -> display battery levels with speaker and leds
    [main.ino]
2023-02-19 Fixed issues in the build and insert script
2023-02-20 Tried connecting lcd display and connected humidity+temp sensor
2023-02-21 Updated script to use an led as well
2023-02-23 Updated insert script
2023-03-04 Fixed problem with submodules, finished website for now, can display graphs for sensors, but not really connected to backend
2023-03-06 Added error message for the case that the json data is null
2023-03-07 New class which pings the wemos in a seperate thread
2023-03-13 Added wiring diagram
2023-03-13 Added bom.md
2023-03-13 Added introduction to bom and wd
2023-03-14 Added physical design files
    [Weather Wizard Final.stl, prototype 0.1.stl, prototype 0.15.stl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]
2023-03-14 Added Fritzing file
    [WD.fzz]
2023-03-14 Updated embedded code -> Now using get request to receive current time
2023-03-15 Changed files again
    [Weather Wizard Final.stl, prototype 0.1.stl, prototype 0.15.stl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]
2023-03-20 Added research to frameworks in golang
2023-03-21 Updated current state of research in the docs
2023-03-23 Updated insert script to postgres dialect
2023-03-23 Added fucntion to run insert script
2023-03-28 Updated daily research docs with current developments
2023-03-31 Switched grafana versions to improve compatability
2023-04-02 Fixed a couple of bugs in the database manager
2023-04-03 Added submit button
2023-04-04 current state of docs
